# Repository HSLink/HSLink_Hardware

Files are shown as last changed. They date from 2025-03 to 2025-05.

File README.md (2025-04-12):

# HSLink_Hardware
用于存放历史HSLink的硬件工程。

## Release Note:

### v1.0

* 初版

### v1.2.0

* 修改了WS2812管脚，与串口控制脚交换，以使用SPI
* 使用负载开关替换替换mos来控制对外输出

### v1.2.1

* 更换负载开关以提高smt良率

### v1.3.1

* 修改外观适配外壳
* 使用sepic替换buck以避免输入5v时输出达不到5v
* 依旧使用mos控制tvcc输出
* 修复下载时可能出现的串口乱码
* 添加io失能串口输出

## 内嵌字体下载

[MiSans](https://hyperos.mi.com/font/download)

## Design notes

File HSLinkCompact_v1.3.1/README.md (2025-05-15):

# HSLinkPro

适配鹿小班等外壳。

## KiCAD 版本

使用9.0以上版本的KiCAD打开。

## 制作指南

[制作指南](./ProductionGuide.md)

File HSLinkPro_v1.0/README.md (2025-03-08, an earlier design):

# HSLinkPro_v1.0

预售版本/第一版本，2024-08-29于淘宝睿赛德科技上架

## KiCAD 版本

使用8.0以上版本的KiCAD打开。

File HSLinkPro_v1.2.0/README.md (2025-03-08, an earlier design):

# HSLinkPro

## 本仓库不再更新！！

新的参考设计: <https://github.com/cherry-embedded/CherryDAP/tree/master/projects/HSLink-Pro/hardware>

HSLink Pro是一款基于HPM5301系列MCU的调试器。最高SWD/JTAG通信速率可达80M，并且拥有一路USB转串口，并带有DTR与RTS的输出，方便某些串口下载的MCU应用。

HSLink Pro软件参考<https://github.com/cherry-embedded/CherryDAP>。

## KiCAD 版本

使用8.0以上版本的KiCAD打开。

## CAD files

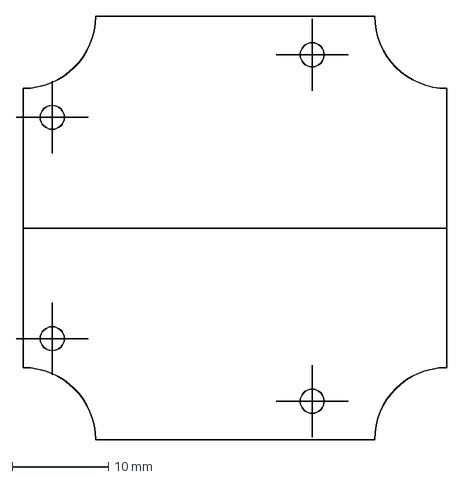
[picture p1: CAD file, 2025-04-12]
HSLinkCompact_v1.3.1/shape.dxf
44.8 x 44.0 mm

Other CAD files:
HSLinkCompact_v1.3.1/shape.DWG

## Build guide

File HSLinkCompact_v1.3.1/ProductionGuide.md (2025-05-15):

# 制作指南

## 制版及贴片

选择你喜欢的板厂打板。

根据自身情况选择smt或者手工焊接。

得到一块焊完的PCB。

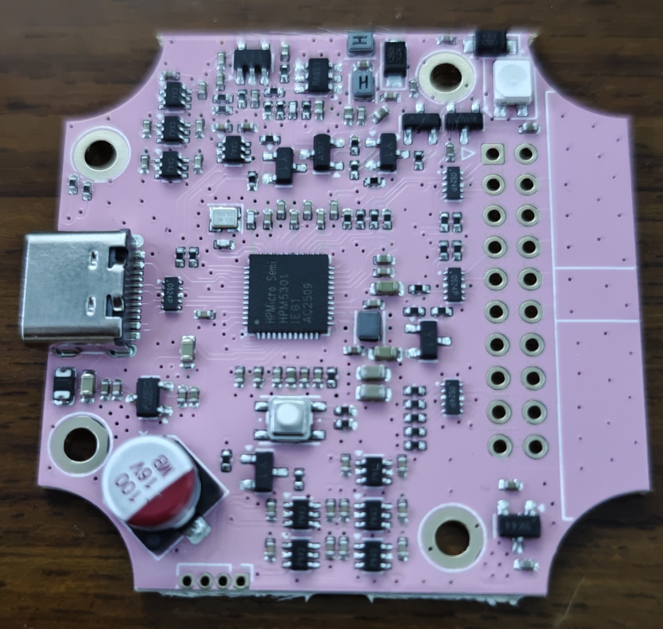
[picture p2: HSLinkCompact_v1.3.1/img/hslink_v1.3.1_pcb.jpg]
hslink_v1.3.1实物图


## 烧录线连接

使用1.27的测试夹，或是直接焊线，将USB转串口连接到PCB左下角的烧录点。参照背面对应位置的丝印，GND连接GND，TX接RX，RX接TX，3V不连接。

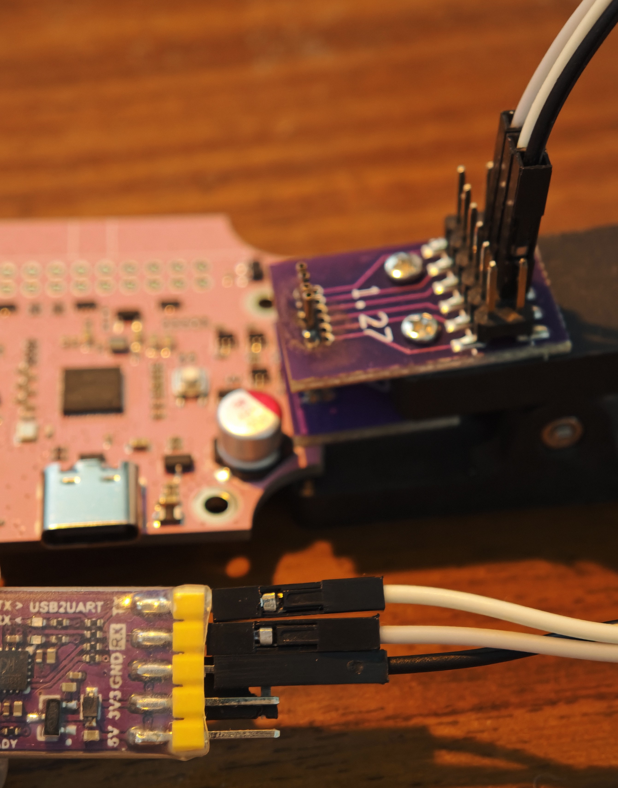
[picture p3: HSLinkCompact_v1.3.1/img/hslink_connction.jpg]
hslink_connction


## 连接电脑烧录

按住按键后插入PCB的Type-C接口，再插入USB转串口的USB接口。

打开HPM的上位机选择对应的串口，速率拉高后点击连接

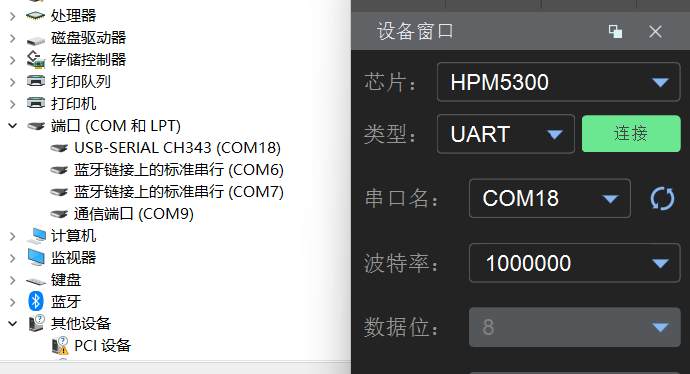
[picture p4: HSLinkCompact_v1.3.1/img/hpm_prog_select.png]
hpmprog


选择固件压缩包中的Merge.bin文件，点击烧写。

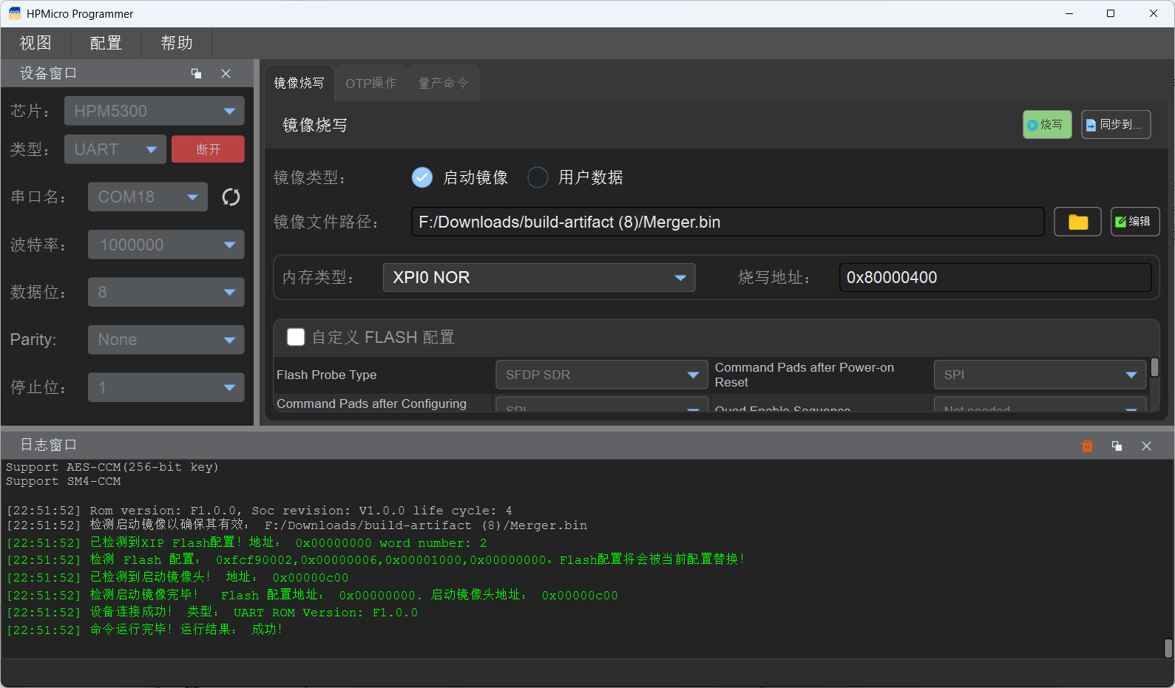
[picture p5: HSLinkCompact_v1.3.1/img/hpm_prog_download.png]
hpm_prog_download


切换到OTP页面，烧写版本号。注意OTP仅能进行一次烧写。

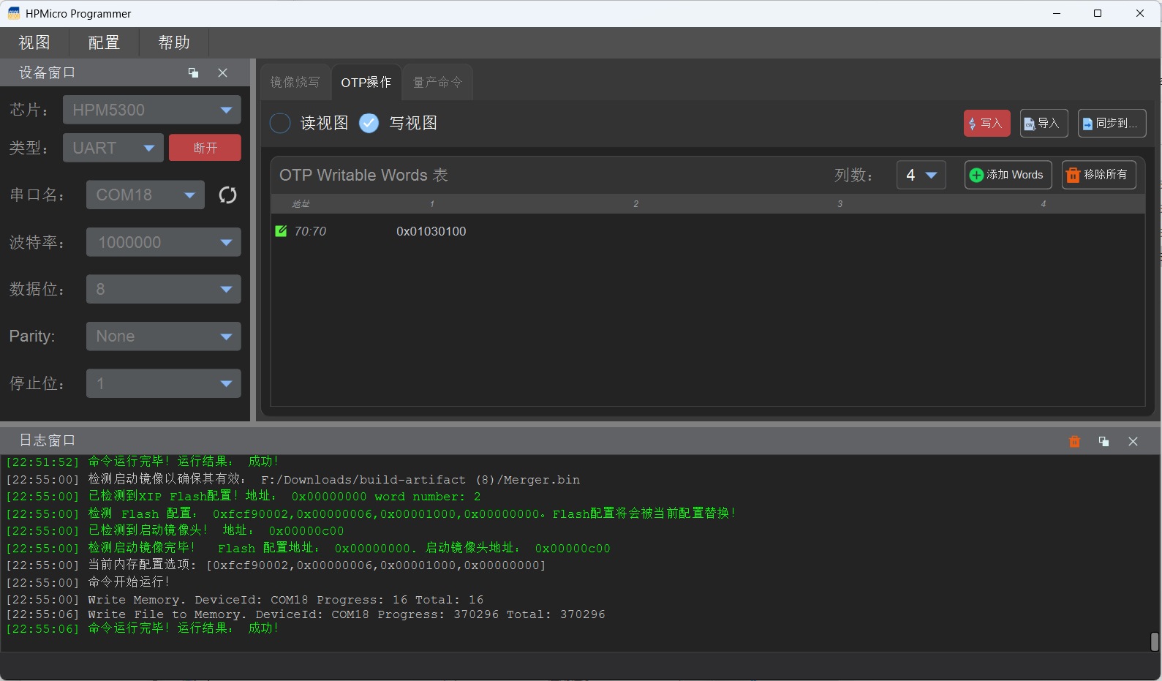
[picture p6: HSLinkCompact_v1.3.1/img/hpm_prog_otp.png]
hpm_prog_otp


## 连接上位机

拔掉调试器再插入，即可连接到上位机

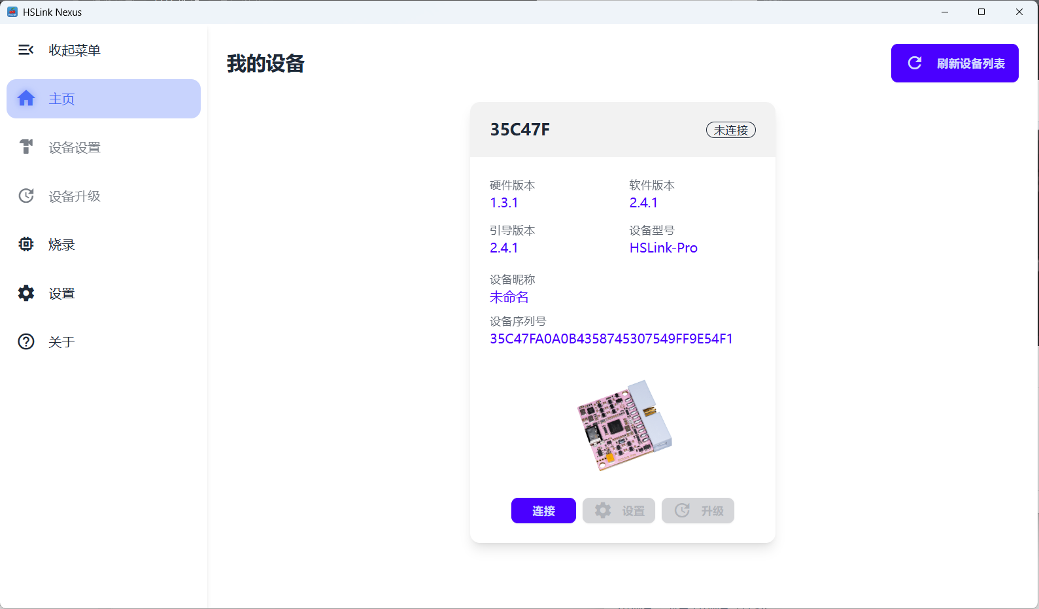
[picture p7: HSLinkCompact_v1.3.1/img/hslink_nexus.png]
hslink_nexus


## 外壳

可配合鹿小班等外壳，使用M2.2*4的自攻螺丝进行固定。

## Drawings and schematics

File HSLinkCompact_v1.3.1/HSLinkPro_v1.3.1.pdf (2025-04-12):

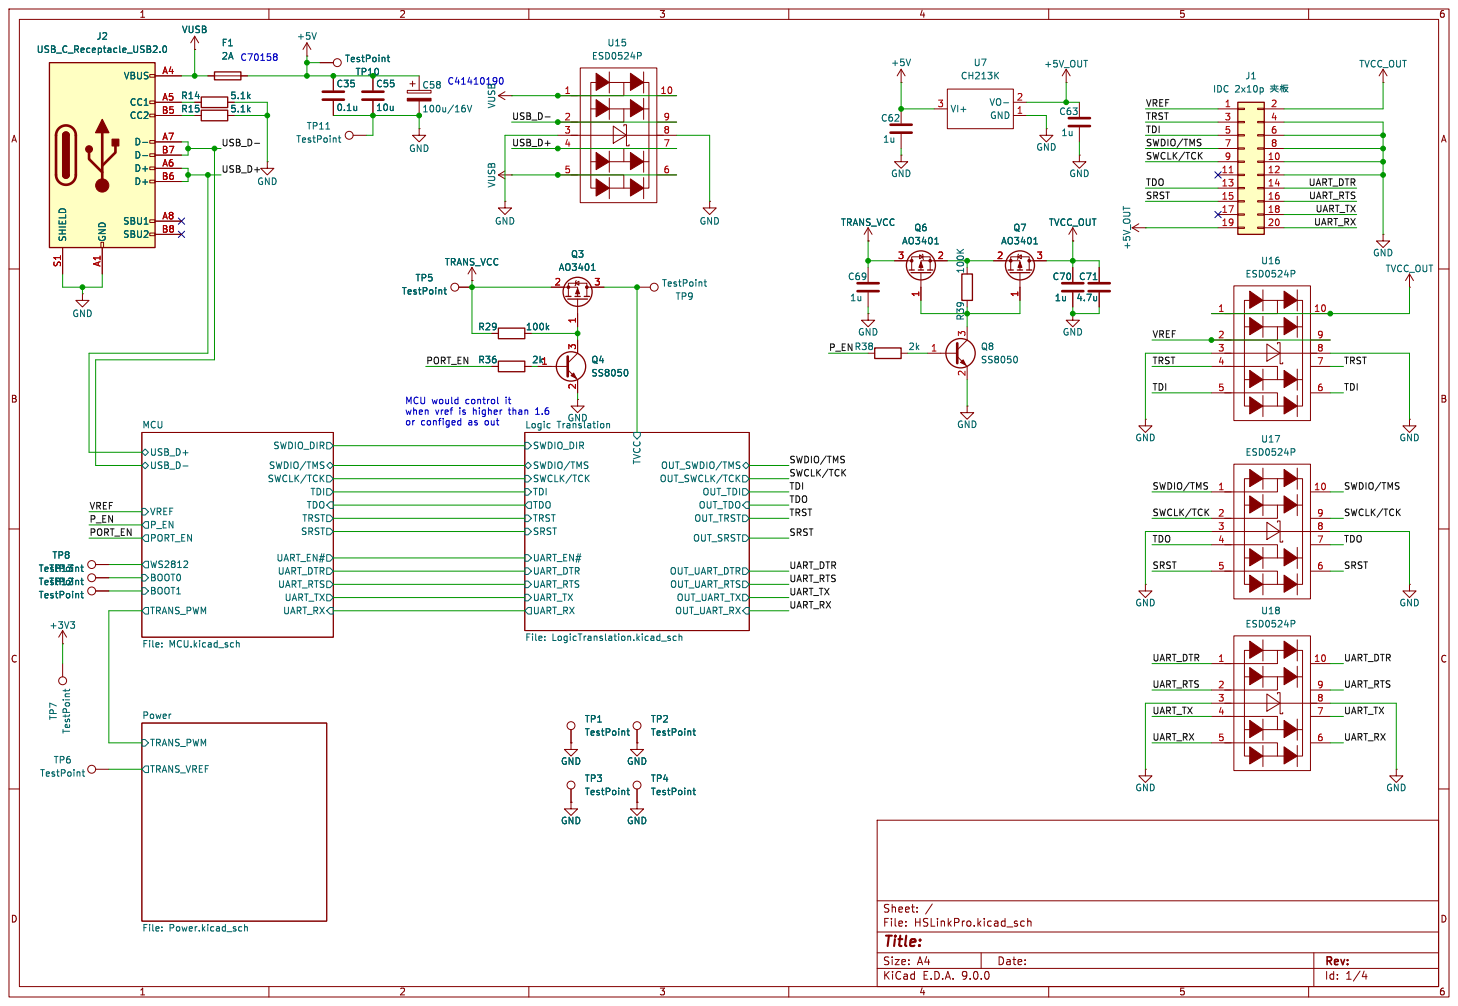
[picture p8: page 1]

Logic Translation File: LogicTranslation.kicad_sch TRANS_PWM

Id: 1/4 Title: File: HSLinkPro.kicad_sch Sheet: /

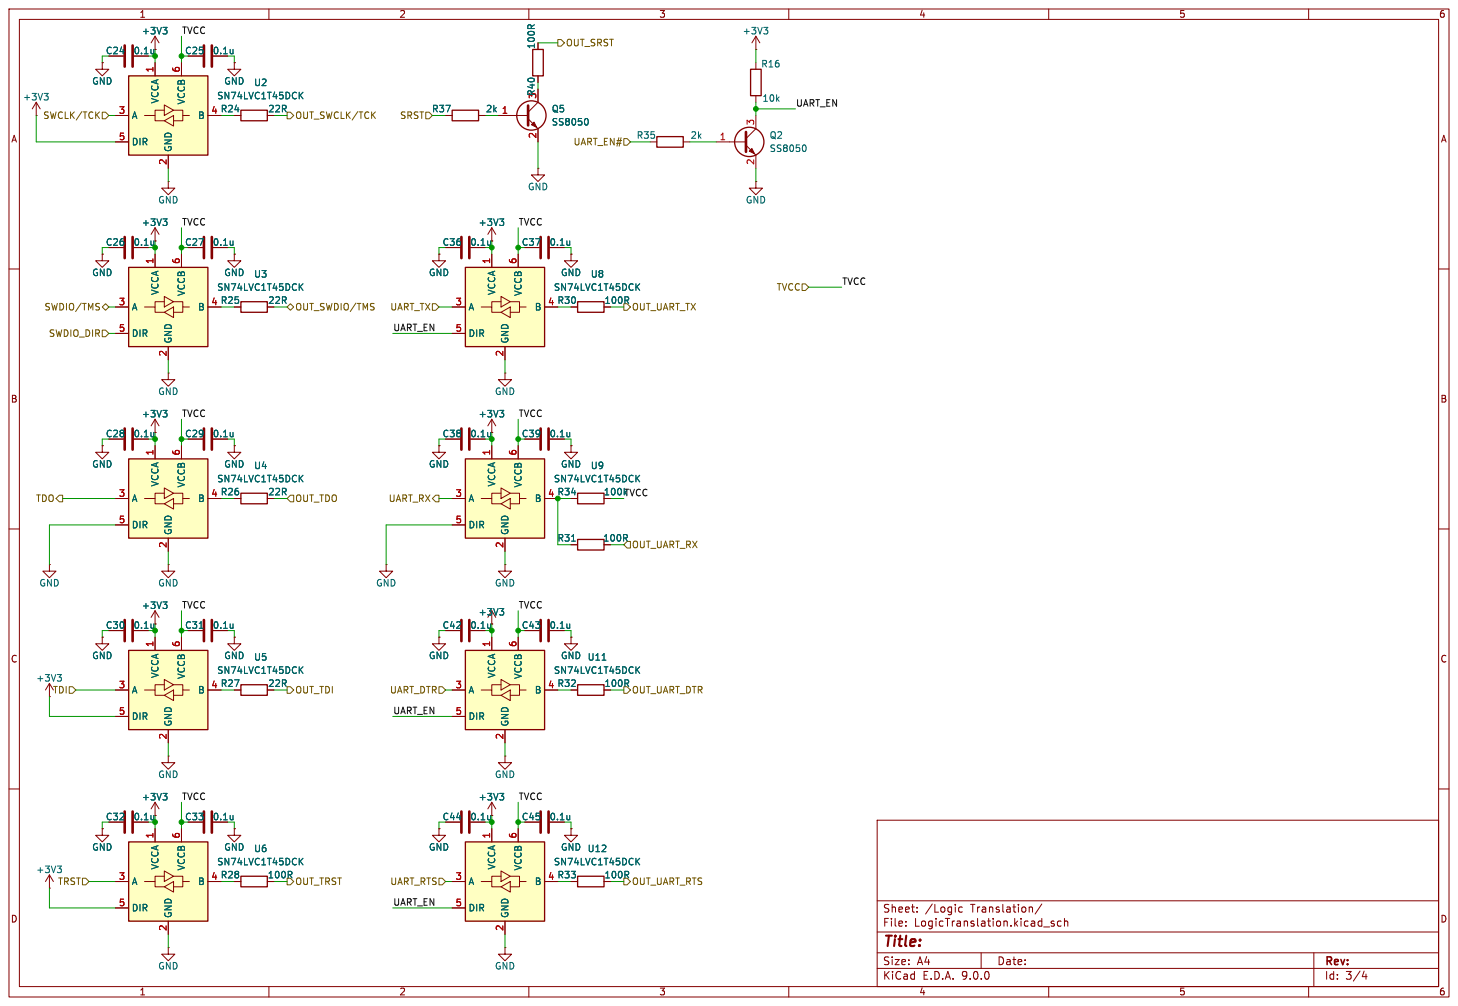
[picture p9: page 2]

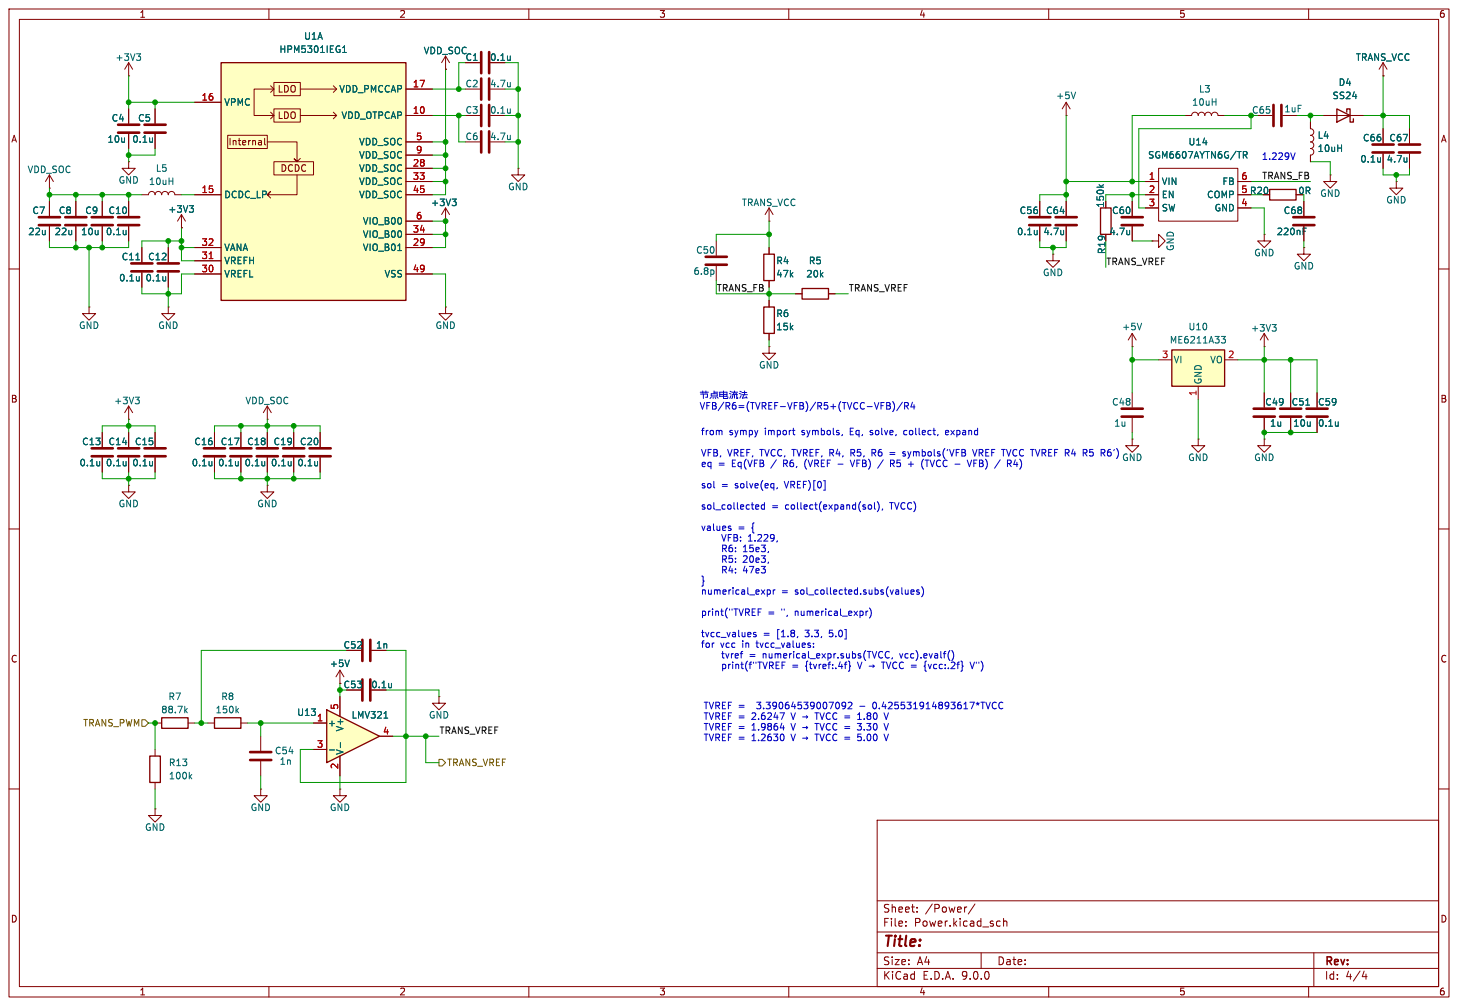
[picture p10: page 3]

þÿ‚‚p¹u5mAlÕ
VFB/R6=(TVREF-VFB)/R5+(TVCC-VFB)/R4

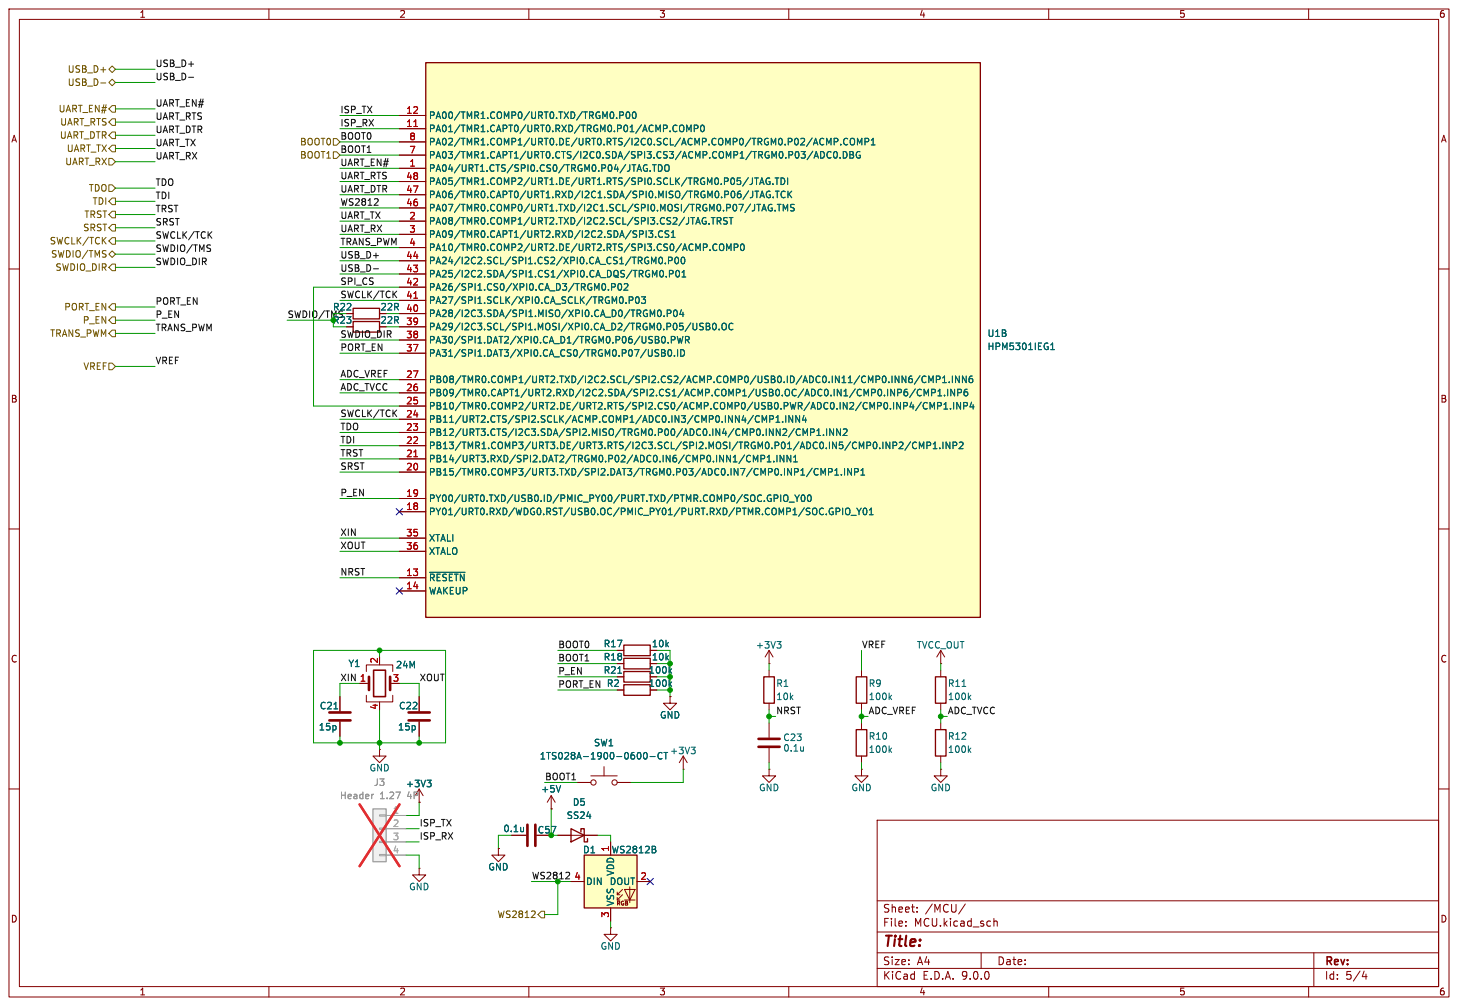
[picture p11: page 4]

TRST SRST SWDIO/TMS

Id: 5/4 Title: File: MCU.kicad_sch Sheet: /MCU/ R11

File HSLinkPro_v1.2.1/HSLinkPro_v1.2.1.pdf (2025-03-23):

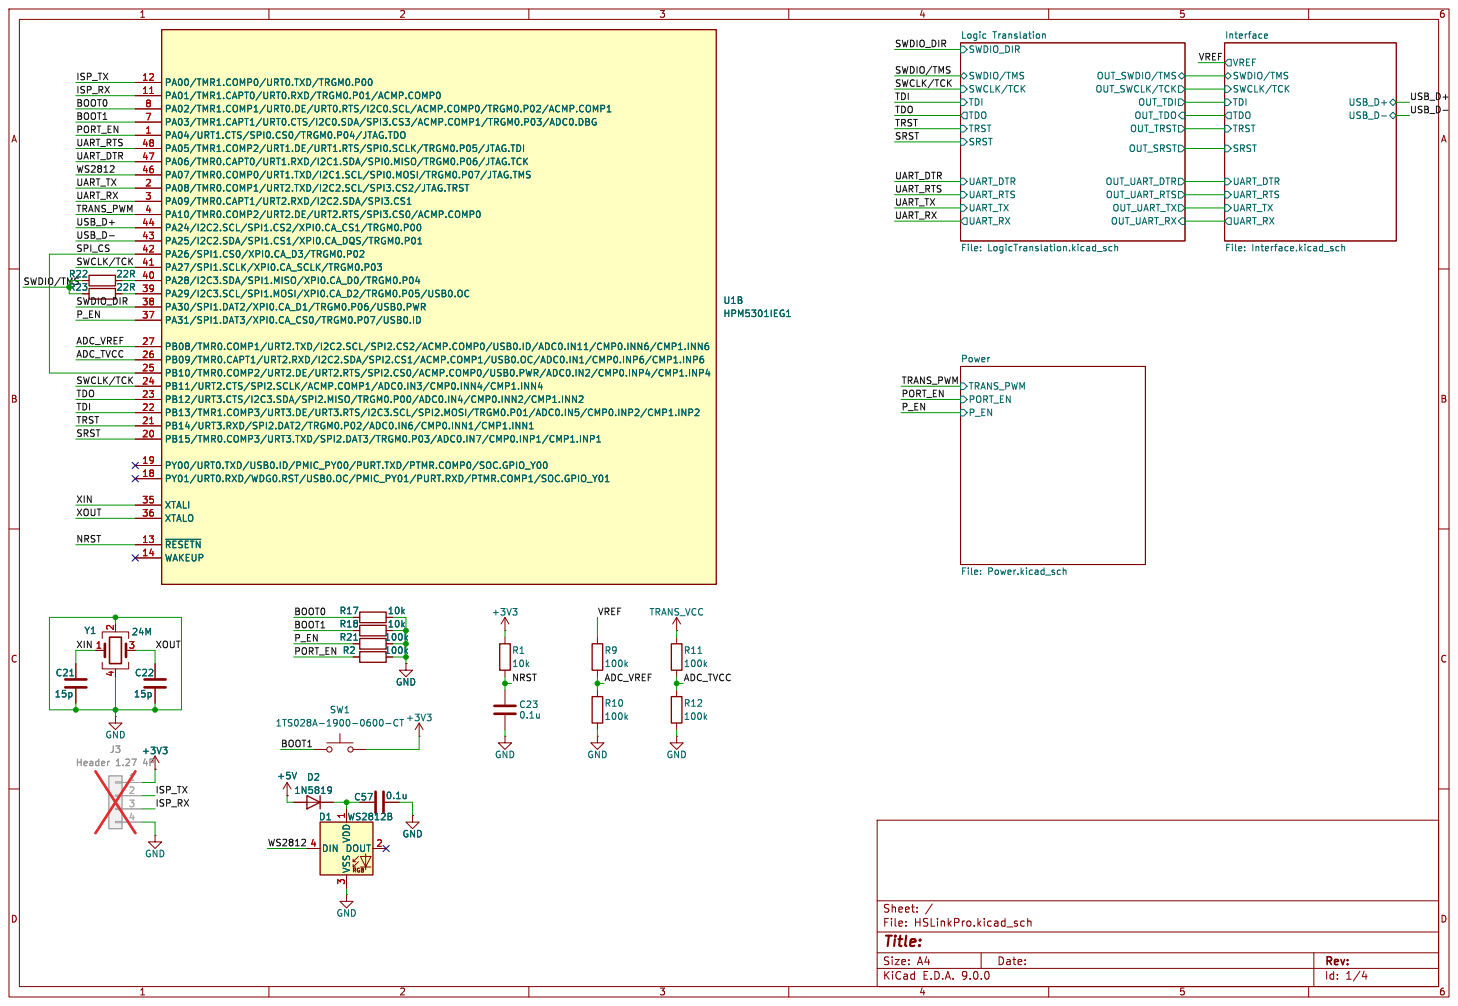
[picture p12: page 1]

Id: 1/4 Title: File: HSLinkPro.kicad_sch Sheet: /

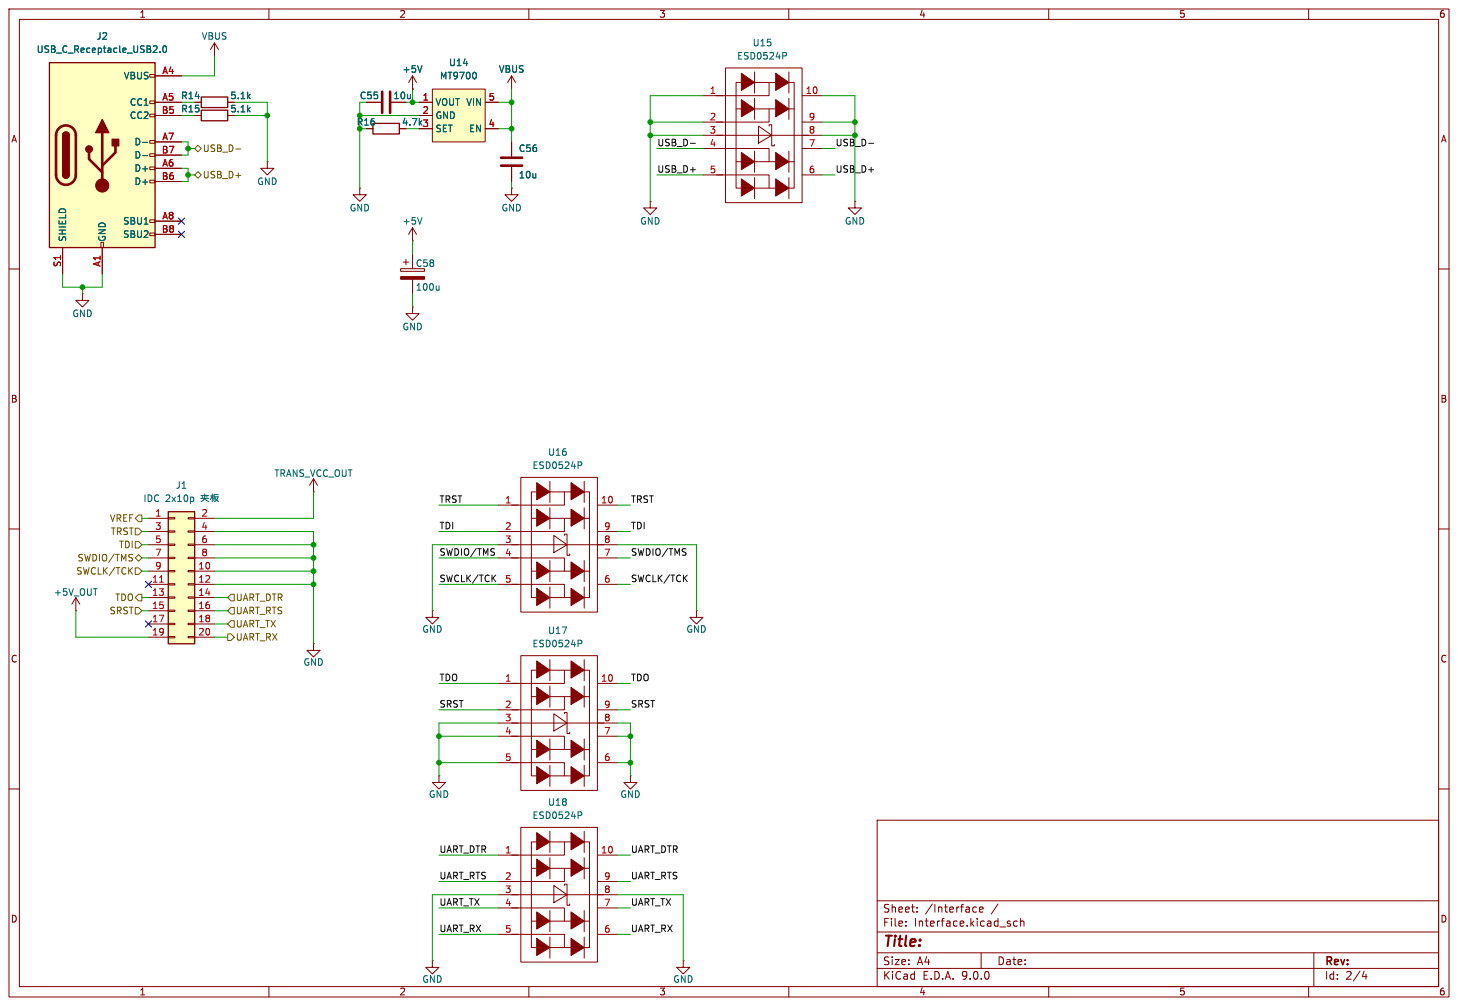
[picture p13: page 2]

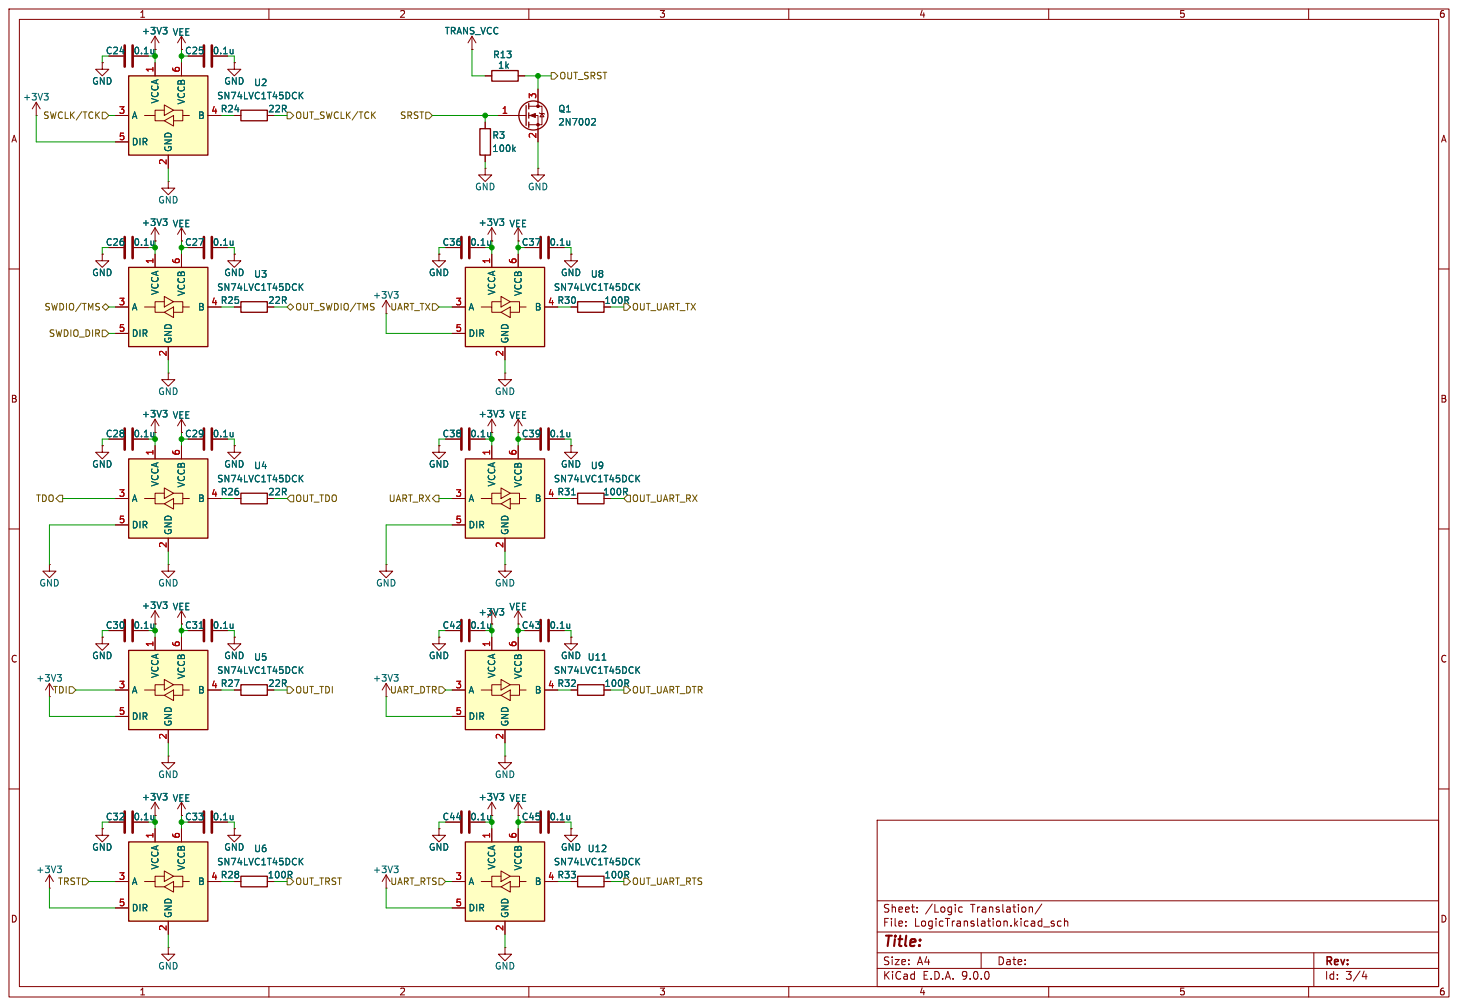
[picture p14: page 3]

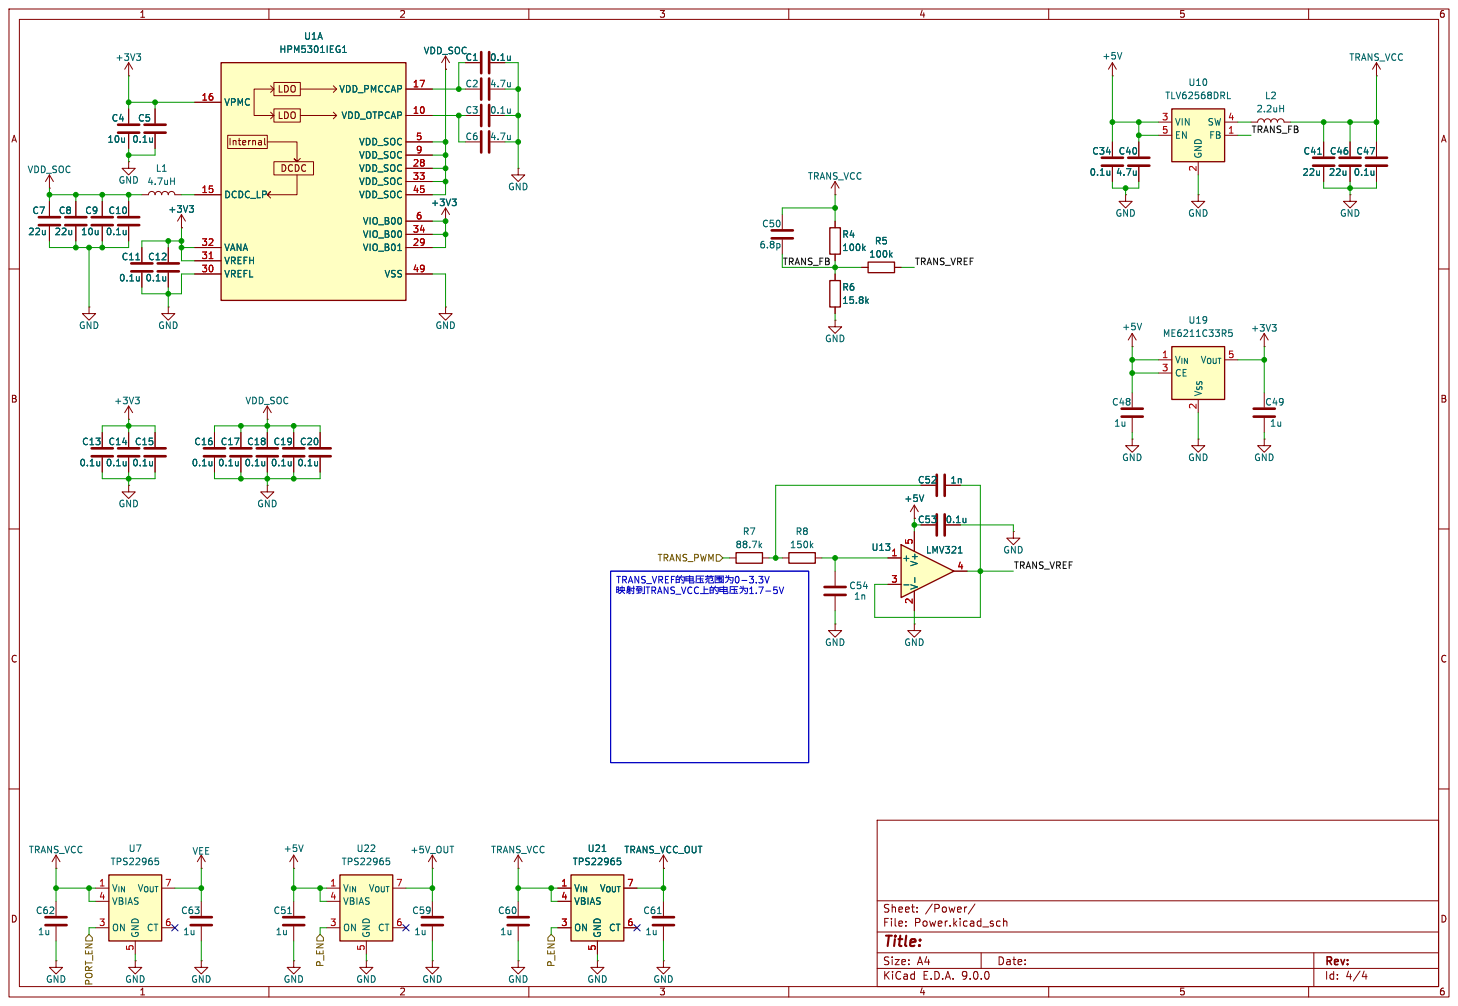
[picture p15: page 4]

2 SW 4 FB 1 U10 TLV62568DRL GND GND

Id: 4/4 Title: File: Power.kicad_sch Sheet: /Power/

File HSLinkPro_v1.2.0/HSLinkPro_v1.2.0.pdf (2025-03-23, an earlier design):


Id: 1/4 Title: File: HSLinkPro.kicad_sch Sheet: /



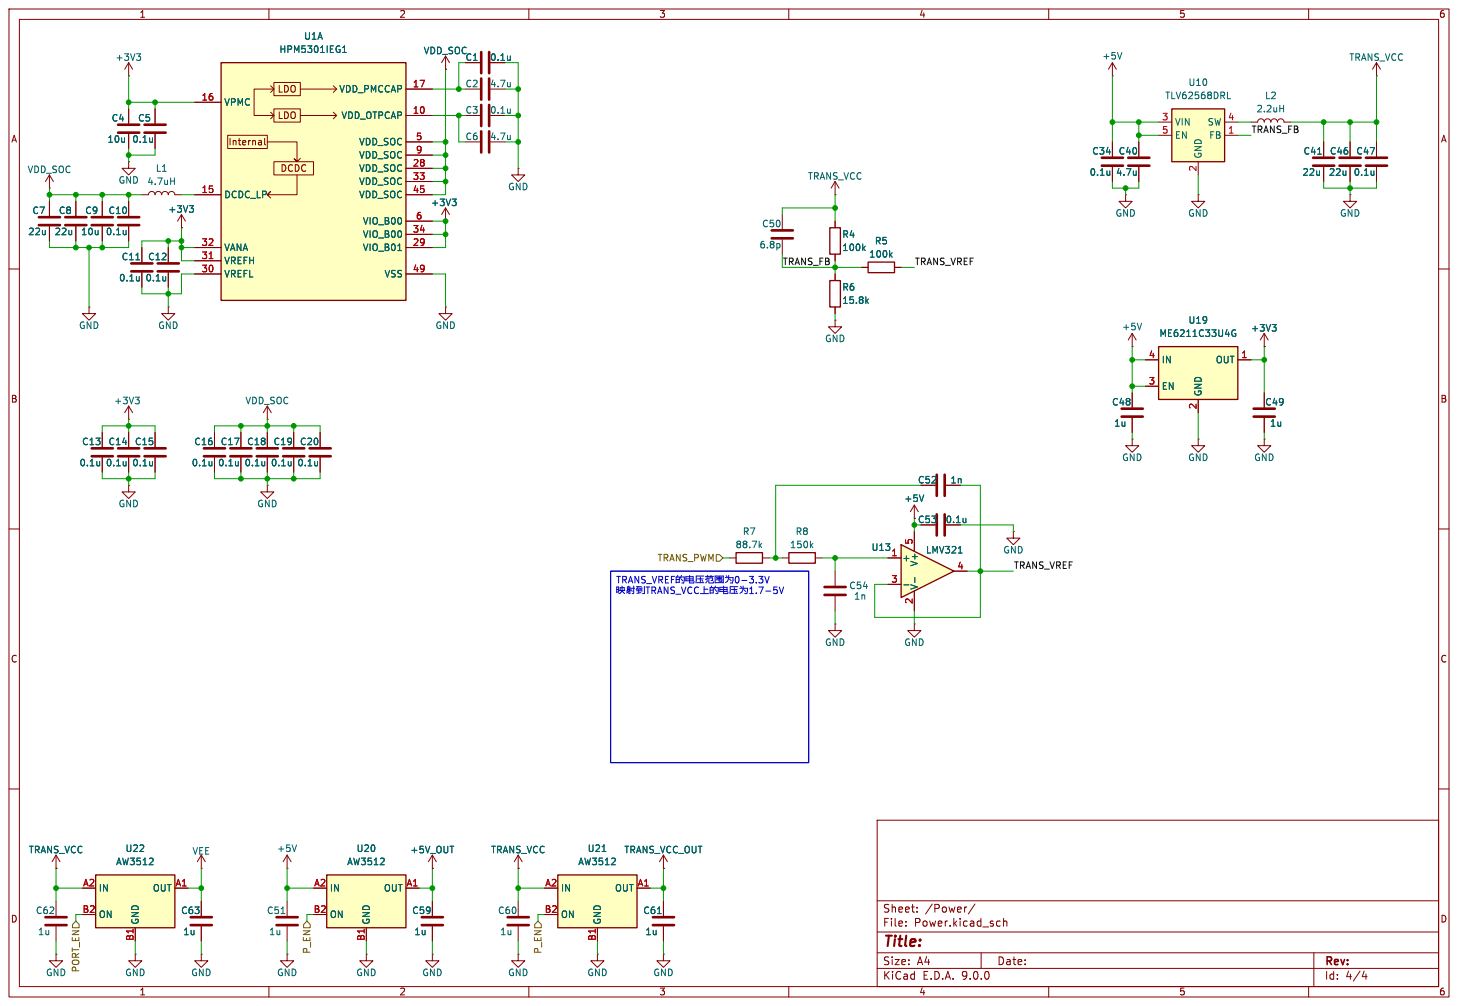
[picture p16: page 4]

Id: 4/4 Title: File: Power.kicad_sch Sheet: /Power/

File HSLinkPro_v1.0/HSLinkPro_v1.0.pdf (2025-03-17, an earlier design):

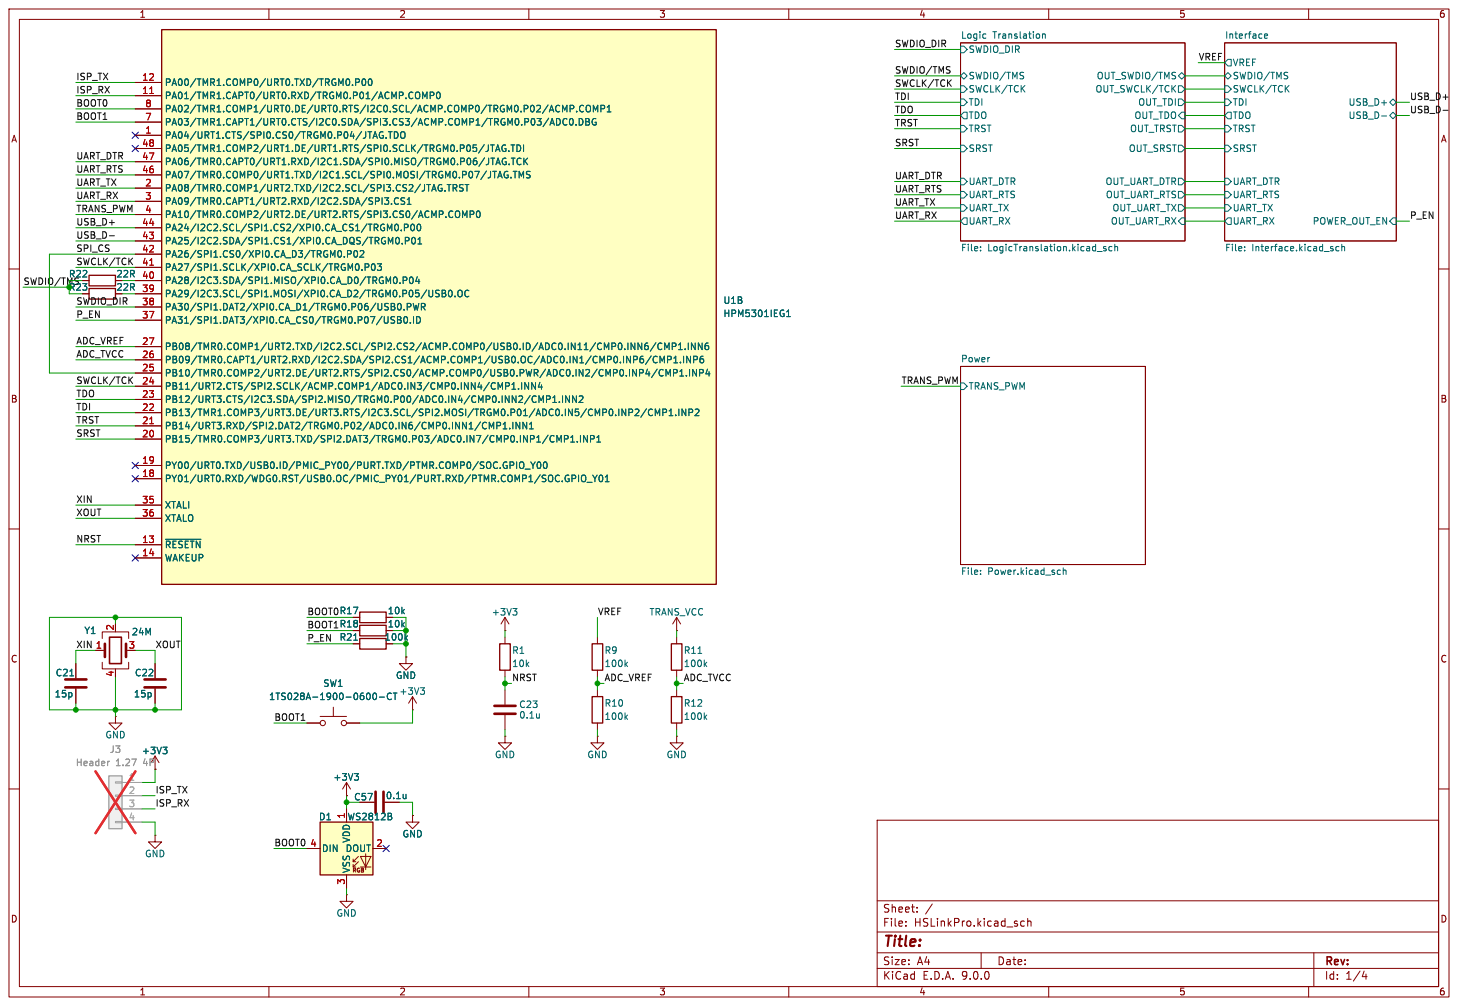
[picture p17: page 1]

Id: 1/4 Title: File: HSLinkPro.kicad_sch Sheet: /

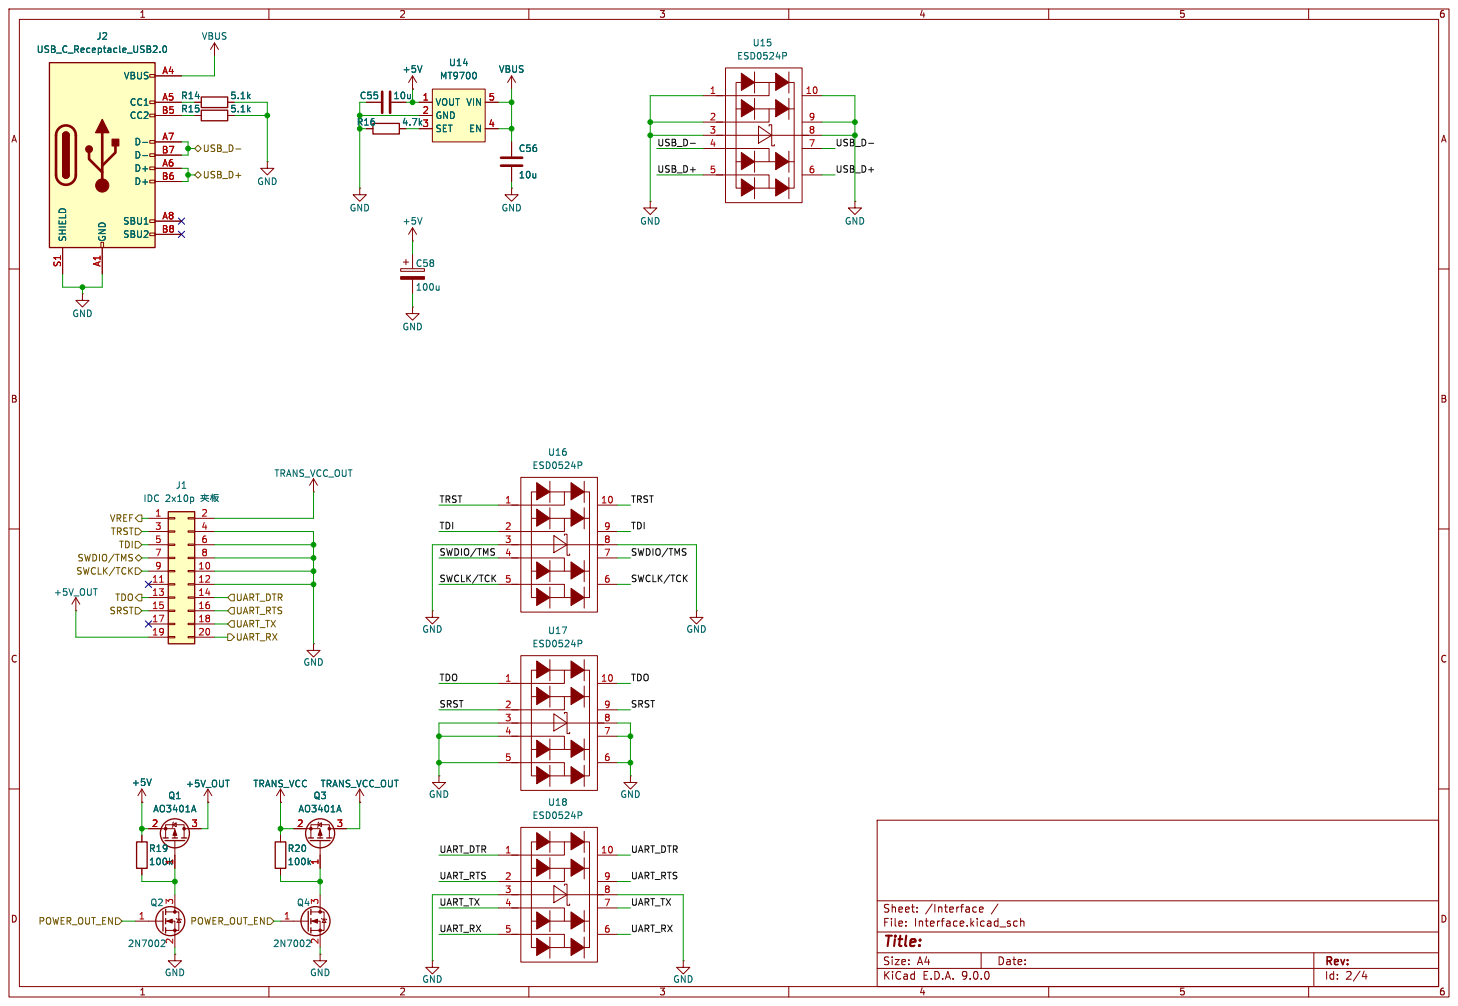
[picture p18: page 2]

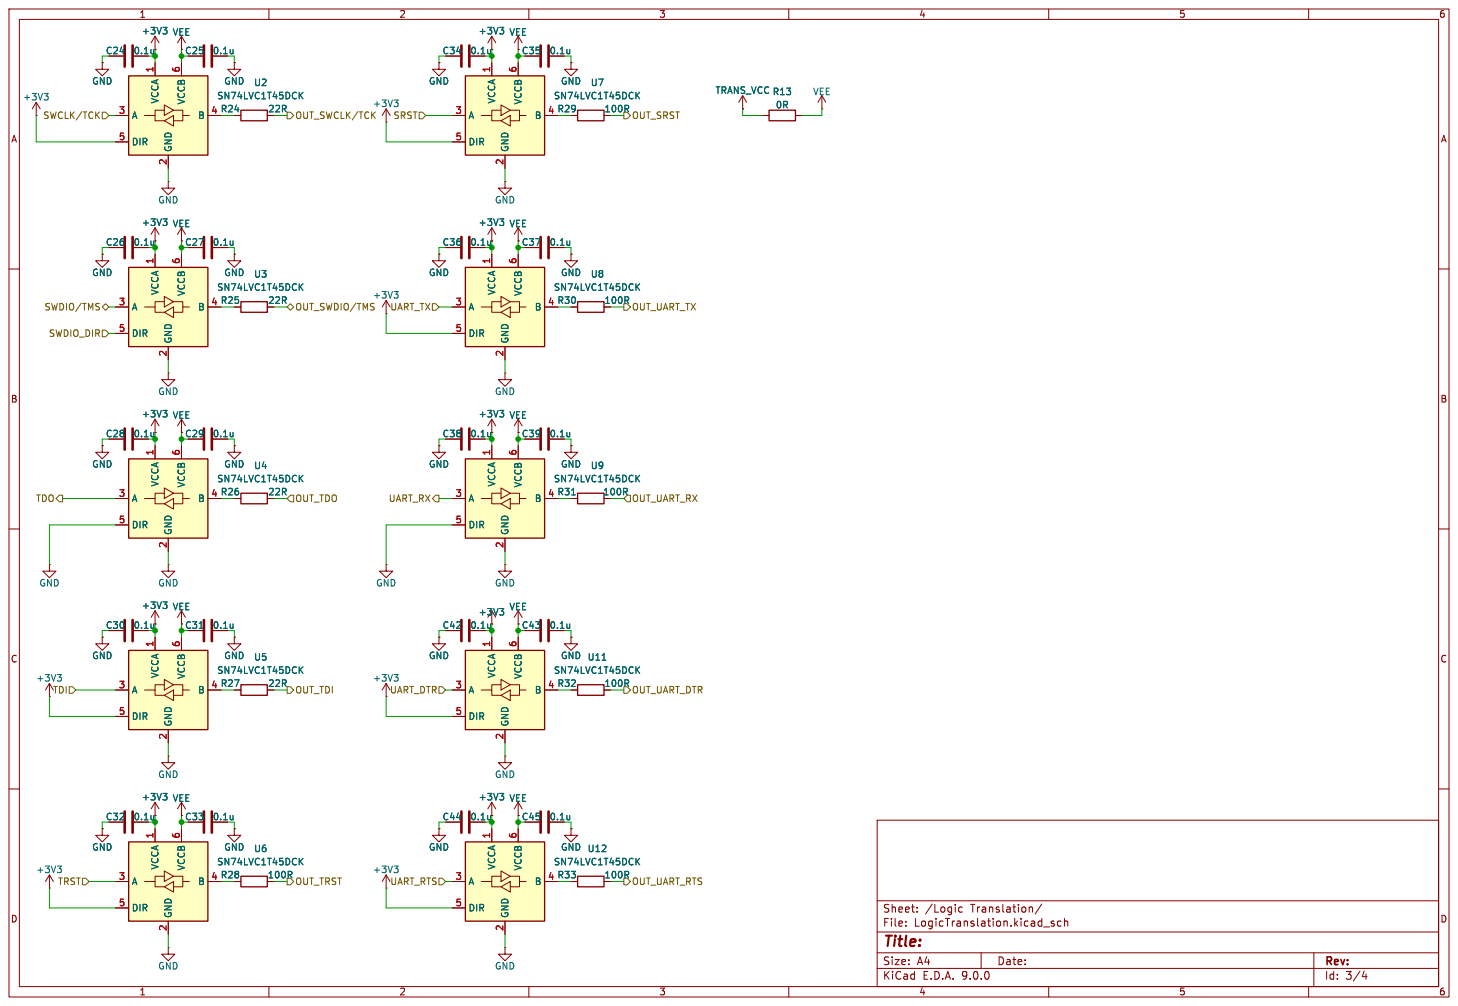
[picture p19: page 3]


Id: 4/4 Title: File: Power.kicad_sch Sheet: /Power/

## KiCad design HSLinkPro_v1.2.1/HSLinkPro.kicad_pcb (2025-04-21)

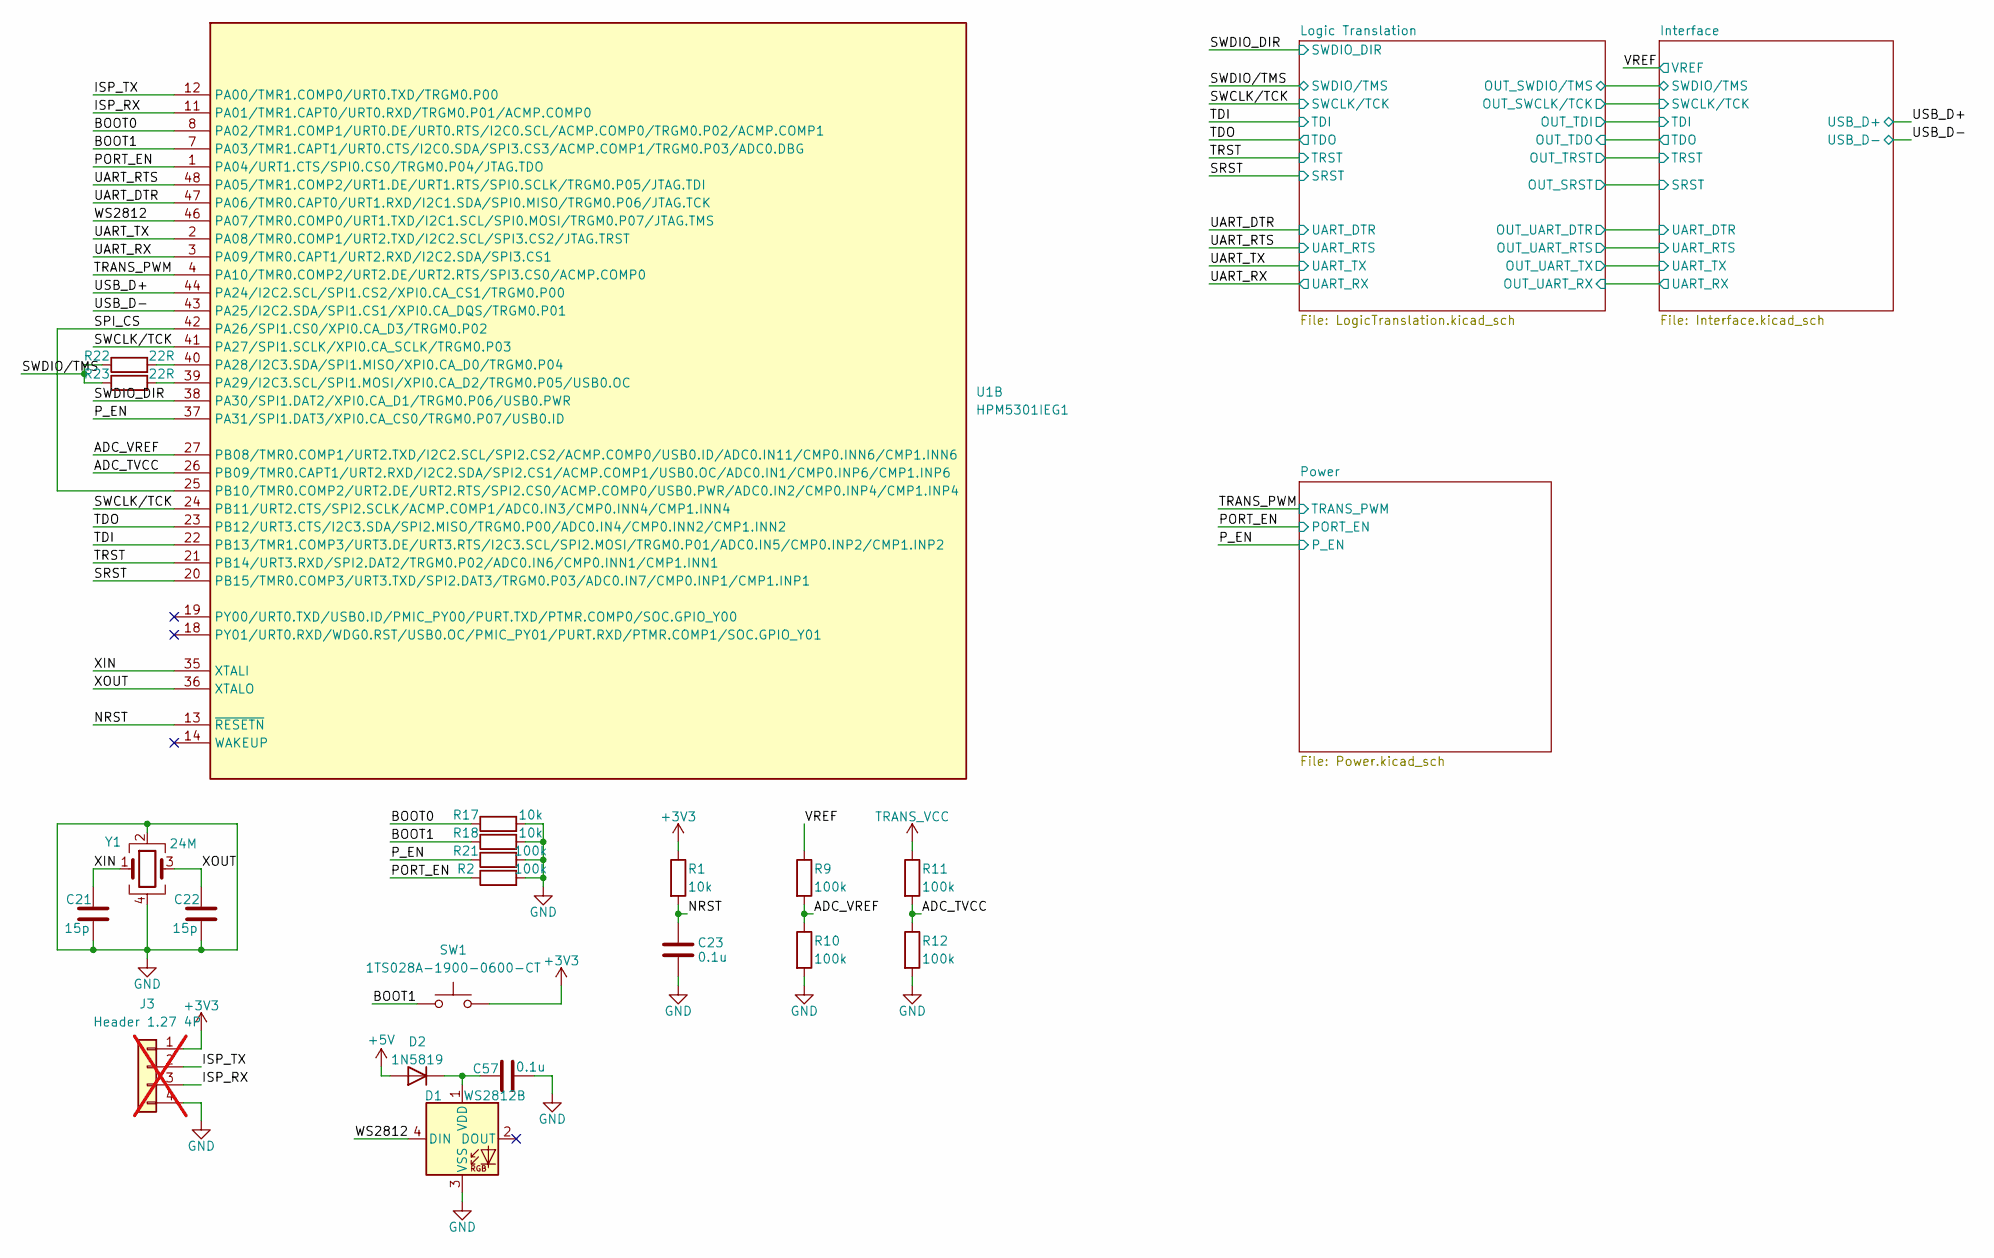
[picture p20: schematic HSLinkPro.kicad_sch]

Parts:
C21, C22: 15p; C_0402_1005Metric
C23, C57: 0.1u; C_0402_1005Metric
D1: WS2812B; LED_WS2812_0807
D2: 1N5819; D_SOD-523
J3: Header 1.27 4P; PinHeader_1x04_P1.27mm_Vertical; not fitted
R1, R17, R18: 10k; R_0402_1005Metric
R2, R9, R10, R11, R12, R21: 100k; R_0402_1005Metric
R22, R23: 22R; R_0402_1005Metric
SW1: 1TS028A-1900-0600-CT; SW-SMD_4P-L2.8-W1.9-P1.20-LS3.0_1TS028A
U1: HPM5301IEG1; QFN-48-1EP_6x6mm_P0.4mm_EP4.2x4.2mm
Y1: 24M; Crystal_SMD_2016-4Pin_2.0x1.6mm

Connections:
+3V3: J3.1, R1.1, SW1.2; also elsewhere on the board
+5V: D2.2 (A); also elsewhere on the board
/ADC_TVCC: R11.2, R12.1, U1.26 (PB09/TMR0.CAPT1/URT2.RXD/I2C2.SDA/SPI2.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)
/ADC_VREF: R9.2, R10.1, U1.27 (PB08/TMR0.COMP1/URT2.TXD/I2C2.SCL/SPI2.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)
/BOOT0: R17.1, U1.8 (PA02/TMR1.COMP1/URT0.DE/URT0.RTS/I2C0.S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)
/BOOT1: R18.1, SW1.1, U1.7 (PA03/TMR1.CAPT1/URT0.CTS/I2C0.SDA/SPI3.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)
/ISP_RX: J3.3, U1.11 (PA01/TMR1.CAPT0/URT0.RXD/TRGM0.P01/ACMP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)
/ISP_TX: J3.2, U1.12 (PA00/TMR1.COMP0/URT0.TXD/TRGM0.P00)
/NRST: C23.1, R1.2, U1.13 (~RESETN)
/PORT_EN: R2.1, U1.1 (PA04/URT1.CTS/SPI0.CS0/TRGM0.P04/JTAG.T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); also elsewhere on the board
/P_EN: R21.1, U1.37 (PA31/SPI1.DAT3/XPI0.CA_CS0/TRGM0.P07/US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); also elsewhere on the board
/SPI_CS: U1.25 (PB10/TMR0.COMP2/URT2.DE/URT2.RTS/SPI2.C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), U1.42 (PA26/SPI1.CS0/XPI0.CA_D3/TRGM0.P02)
/SRST: U1.20 (PB15/TMR0.COMP3/URT3.TXD/SPI2.DAT3/TRGM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); also elsewhere on the board
/SWCLK/TCK: U1.24 (PB11/URT2.CTS/SPI2.SCLK/ACMP.COMP1/ADC0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), U1.41 (PA27/SPI1.SCLK/XPI0.CA_SCLK/TRGM0.P03); also elsewhere on the board
/SWDIO_DIR: U1.38 (PA30/SPI1.DAT2/XPI0.CA_D1/TRGM0.P06/USB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); also elsewhere on the board
/SWDIO/TMS: R22.1, R23.1; also elsewhere on the board
/TDI: U1.22 (PB13/TMR1.COMP3/URT3.DE/URT3.RTS/I2C3.S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); also elsewhere on the board
/TDO: U1.23 (PB12/URT3.CTS/I2C3.SDA/SPI2.MISO/TRGM0.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); also elsewhere on the board
/TRANS_PWM: U1.4 (PA10/TMR0.COMP2/URT2.DE/URT2.RTS/SPI3.C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); also elsewhere on the board
/TRST: U1.21 (PB14/URT3.RXD/SPI2.DAT2/TRGM0.P02/ADC0.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); also elsewhere on the board
/UART_DTR: U1.47 (PA06/TMR0.CAPT0/URT1.RXD/I2C1.SDA/SPI0.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); also elsewhere on the board
/UART_RTS: U1.48 (PA05/TMR1.COMP2/URT1.DE/URT1.RTS/SPI0.S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); also elsewhere on the board
/UART_RX: U1.3 (PA09/TMR0.CAPT1/URT2.RXD/I2C2.SDA/SPI3.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); also elsewhere on the board
/UART_TX: U1.2 (PA08/TMR0.COMP1/URT2.TXD/I2C2.SCL/SPI3.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); also elsewhere on the board
/USB_D+: U1.44 (PA24/I2C2.SCL/SPI1.CS2/XPI0.CA_CS1/TRGM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); also elsewhere on the board
/USB_D-: U1.43 (PA25/I2C2.SDA/SPI1.CS1/XPI0.CA_DQS/TRGM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); also elsewhere on the board
/VREF: R9.1; also elsewhere on the board
/WS2812: D1.4 (DIN), U1.46 (PA07/TMR0.COMP0/URT1.TXD/I2C1.SCL/SPI0.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)
/XIN: C21.1, U1.35 (XTALI), Y1.1
/XOUT: C22.1, U1.36 (XTALO), Y1.3
GND: C21.2, C22.2, C23.2, C57.2, D1.3 (VSS), J3.4, R2.2, R10.2, R12.2, R17.2, R18.2, R21.2, Y1.2, Y1.4; also elsewhere on the board
unnamed: C57.1, D1.1 (VDD), D2.1 (K)
unnamed: R22.2, U1.40 (PA28/I2C3.SDA/SPI1.MISO/XPI0.CA_D0/TRGM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)
unnamed: R23.2, U1.39 (PA29/I2C3.SCL/SPI1.MOSI/XPI0.CA_D2/TRGM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)
TRANS_VCC: R11.1; also elsewhere on the board

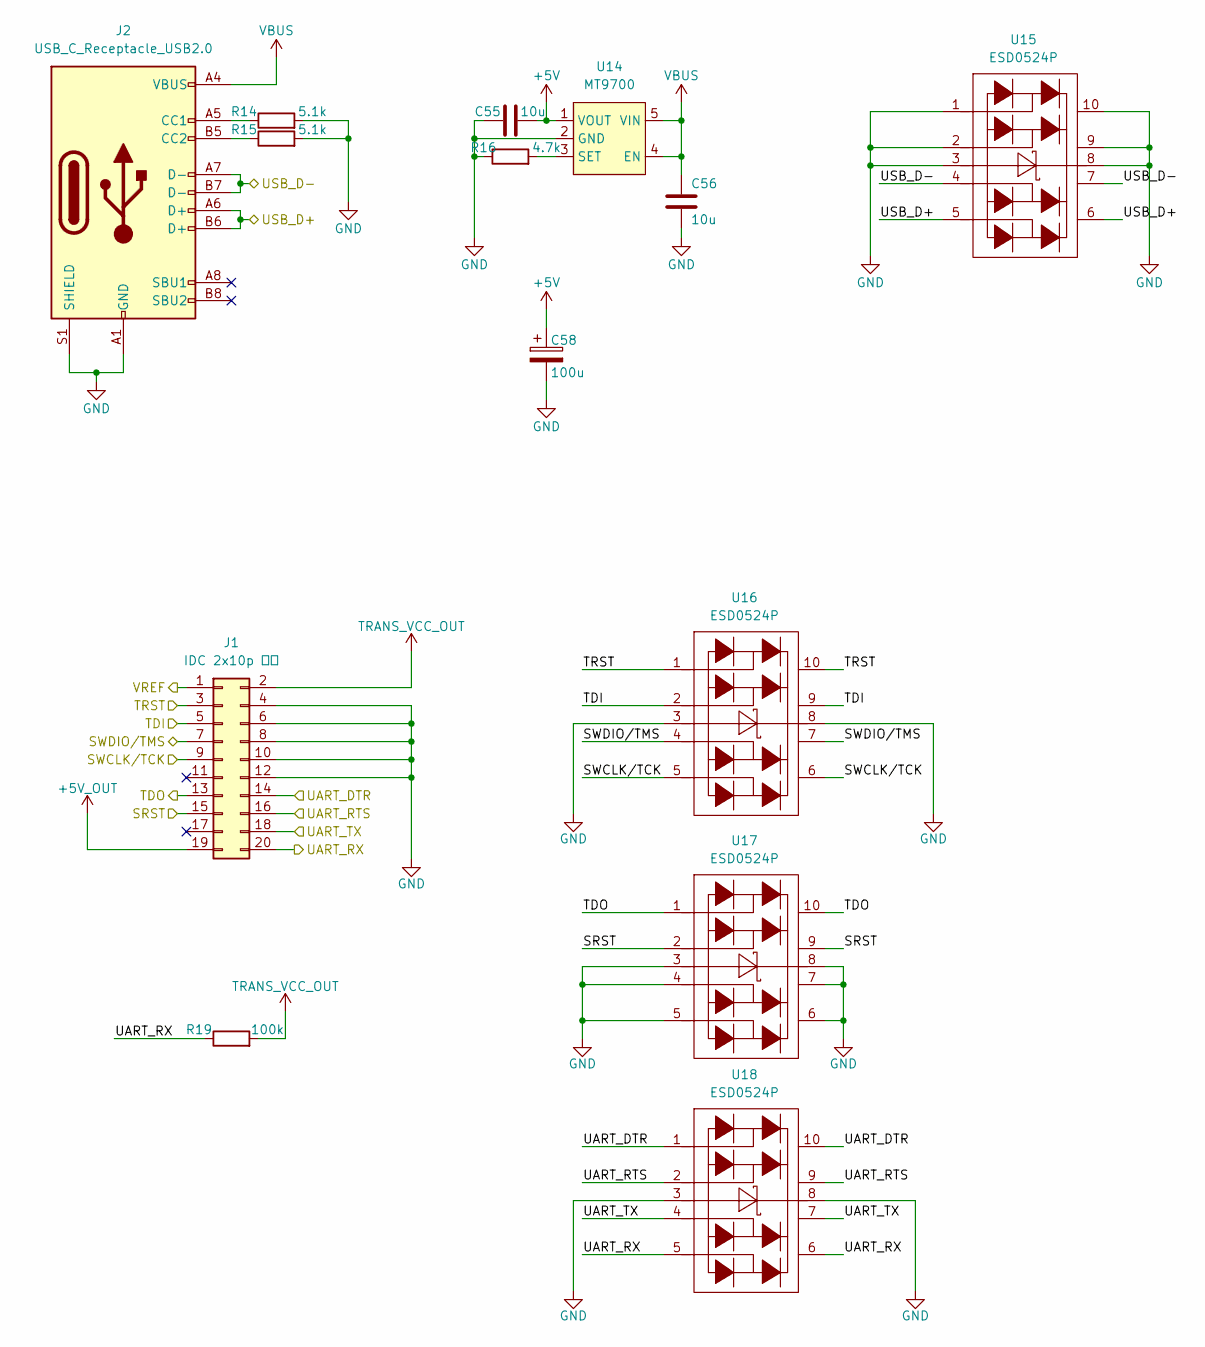
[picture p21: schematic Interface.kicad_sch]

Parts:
C55, C56: 10u; C_0603_1608Metric
C58: 100u; CP_EIA-3528-21_Kemet-B
J1: IDC 2x10p 夹板; Conn_02x10_IDC_SMD
J2: USB_C_Receptacle_USB2.0; USB-C-SMD_CX90M-16P
R14, R15: 5.1k; R_0402_1005Metric
R16: 4.7k; R_0402_1005Metric
R19: 100k; R_0402_1005Metric
U14: MT9700; SOT-23-5
U15, U16, U17, U18: ESD0524P; DFN-10_L2.5-W1.0-P0.50-BL-A

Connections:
+5V: C55.2, C58.1, U14.1 (VOUT); also elsewhere on the board
+5V_OUT: J1.19; also elsewhere on the board
/Interface /<NO NET>: J1.5, U16.2, U16.9; also elsewhere on the board
/Interface /SRST: J1.15, U17.2, U17.9; also elsewhere on the board
/Interface /SWCLK/TCK: J1.9, U16.5, U16.6; also elsewhere on the board
/Interface /SWDIO/TMS: J1.7, U16.4, U16.7; also elsewhere on the board
/Interface /TDO: J1.13, U17.1, U17.10; also elsewhere on the board
/Interface /TRST: J1.3, U16.1, U16.10; also elsewhere on the board
/Interface /UART_DTR: J1.14, U18.1, U18.10; also elsewhere on the board
/Interface /UART_RTS: J1.16, U18.2, U18.9; also elsewhere on the board
/Interface /UART_RX: J1.20, R19.1, U18.5, U18.6; also elsewhere on the board
/Interface /UART_TX: J1.18, U18.4, U18.7; also elsewhere on the board
/USB_D+: J2.A6 (D+), J2.B6 (D+), U15.5, U15.6; also elsewhere on the board
/USB_D-: J2.A7 (D-), J2.B7 (D-), U15.4, U15.7; also elsewhere on the board
/VREF: J1.1; also elsewhere on the board
GND: C55.1, C56.2, C58.2, J1.4, J1.6, J1.8, J1.10, J1.12, J2.A1 (GND), J2.A12 (GND), J2.B1 (GND), J2.B12 (GND), J2.S1 (SHIELD), R14.2, R15.2, R16.1, U14.2 (GND), U15.1, U15.2, U15.3, U15.8, U15.9, U15.10, U16.3, U16.8, U17.3, U17.4, U17.5, U17.6, U17.7, U17.8, U18.3, U18.8; also elsewhere on the board
unnamed: J2.A5 (CC1), R14.1
unnamed: J2.B5 (CC2), R15.1
unnamed: R16.2, U14.3 (SET)
TRANS_VCC_OUT: J1.2, R19.2; also elsewhere on the board
VBUS: C56.1, J2.A4 (VBUS), J2.A9 (VBUS), J2.B4 (VBUS), J2.B9 (VBUS), U14.4 (EN), U14.5 (VIN)

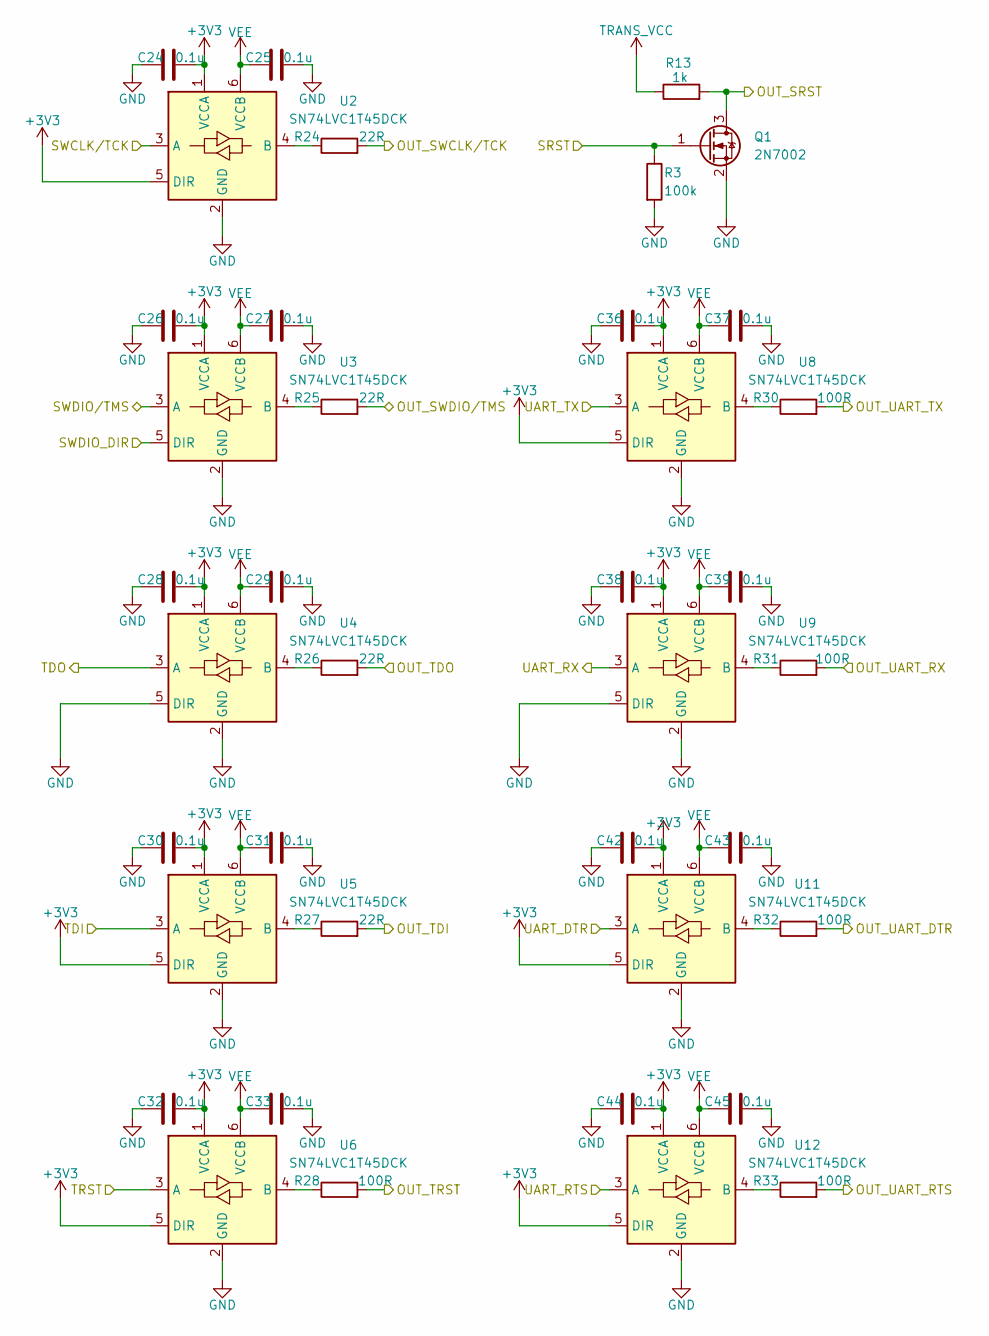
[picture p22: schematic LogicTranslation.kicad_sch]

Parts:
C24, C25, C26, C27, C28, C29, C30, C31, C32, C33, C36, C37, C38, C39, C42, C43, C44, C45: 0.1u; C_0402_1005Metric
Q1: 2N7002; SOT-323_SC-70
R3: 100k; R_0402_1005Metric
R13: 1k; R_0402_1005Metric
R24, R25, R26, R27: 22R; R_0402_1005Metric
R28, R30, R31, R32, R33: 100R; R_0402_1005Metric
U2, U3, U4, U5, U6, U8, U9, U11, U12: SN74LVC1T45DCK; SOT-363_SC-70-6

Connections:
+3V3: C24.2, C26.2, C28.2, C30.2, C32.2, C36.2, C38.2, C42.2, C44.2, U2.1 (VCCA), U2.5 (DIR), U3.1 (VCCA), U4.1 (VCCA), U5.1 (VCCA), U5.5 (DIR), U6.1 (VCCA), U6.5 (DIR), U8.1 (VCCA), U8.5 (DIR), U9.1 (VCCA), U11.1 (VCCA), U11.5 (DIR), U12.1 (VCCA), U12.5 (DIR); also elsewhere on the board
/Interface /<NO NET>: R27.2; also elsewhere on the board
/Interface /SRST: Q1.3 (D), R13.2; also elsewhere on the board
/Interface /SWCLK/TCK: R24.2; also elsewhere on the board
/Interface /SWDIO/TMS: R25.2; also elsewhere on the board
/Interface /TDO: R26.2; also elsewhere on the board
/Interface /TRST: R28.2; also elsewhere on the board
/Interface /UART_DTR: R32.2; also elsewhere on the board
/Interface /UART_RTS: R33.2; also elsewhere on the board
/Interface /UART_RX: R31.2; also elsewhere on the board
/Interface /UART_TX: R30.2; also elsewhere on the board
/SRST: Q1.1 (G), R3.1; also elsewhere on the board
/SWCLK/TCK: U2.3 (A); also elsewhere on the board
/SWDIO_DIR: U3.5 (DIR); also elsewhere on the board
/SWDIO/TMS: U3.3 (A); also elsewhere on the board
/TDI: U5.3 (A); also elsewhere on the board
/TDO: U4.3 (A); also elsewhere on the board
/TRST: U6.3 (A); also elsewhere on the board
/UART_DTR: U11.3 (A); also elsewhere on the board
/UART_RTS: U12.3 (A); also elsewhere on the board
/UART_RX: U9.3 (A); also elsewhere on the board
/UART_TX: U8.3 (A); also elsewhere on the board
GND: C24.1, C25.2, C26.1, C27.2, C28.1, C29.2, C30.1, C31.2, C32.1, C33.2, C36.1, C37.2, C38.1, C39.2, C42.1, C43.2, C44.1, C45.2, Q1.2 (S), R3.2, U2.2 (GND), U3.2 (GND), U4.2 (GND), U4.5 (DIR), U5.2 (GND), U6.2 (GND), U8.2 (GND), U9.2 (GND), U9.5 (DIR), U11.2 (GND), U12.2 (GND); also elsewhere on the board
unnamed: R24.1, U2.4 (B)
unnamed: R25.1, U3.4 (B)
unnamed: R26.1, U4.4 (B)
unnamed: R27.1, U5.4 (B)
unnamed: R28.1, U6.4 (B)
unnamed: R30.1, U8.4 (B)
unnamed: R31.1, U9.4 (B)
unnamed: R32.1, U11.4 (B)
unnamed: R33.1, U12.4 (B)
TRANS_VCC: R13.1; also elsewhere on the board
VEE: C25.1, C27.1, C29.1, C31.1, C33.1, C37.1, C39.1, C43.1, C45.1, U2.6 (VCCB), U3.6 (VCCB), U4.6 (VCCB), U5.6 (VCCB), U6.6 (VCCB), U8.6 (VCCB), U9.6 (VCCB), U11.6 (VCCB), U12.6 (VCCB); also elsewhere on the board

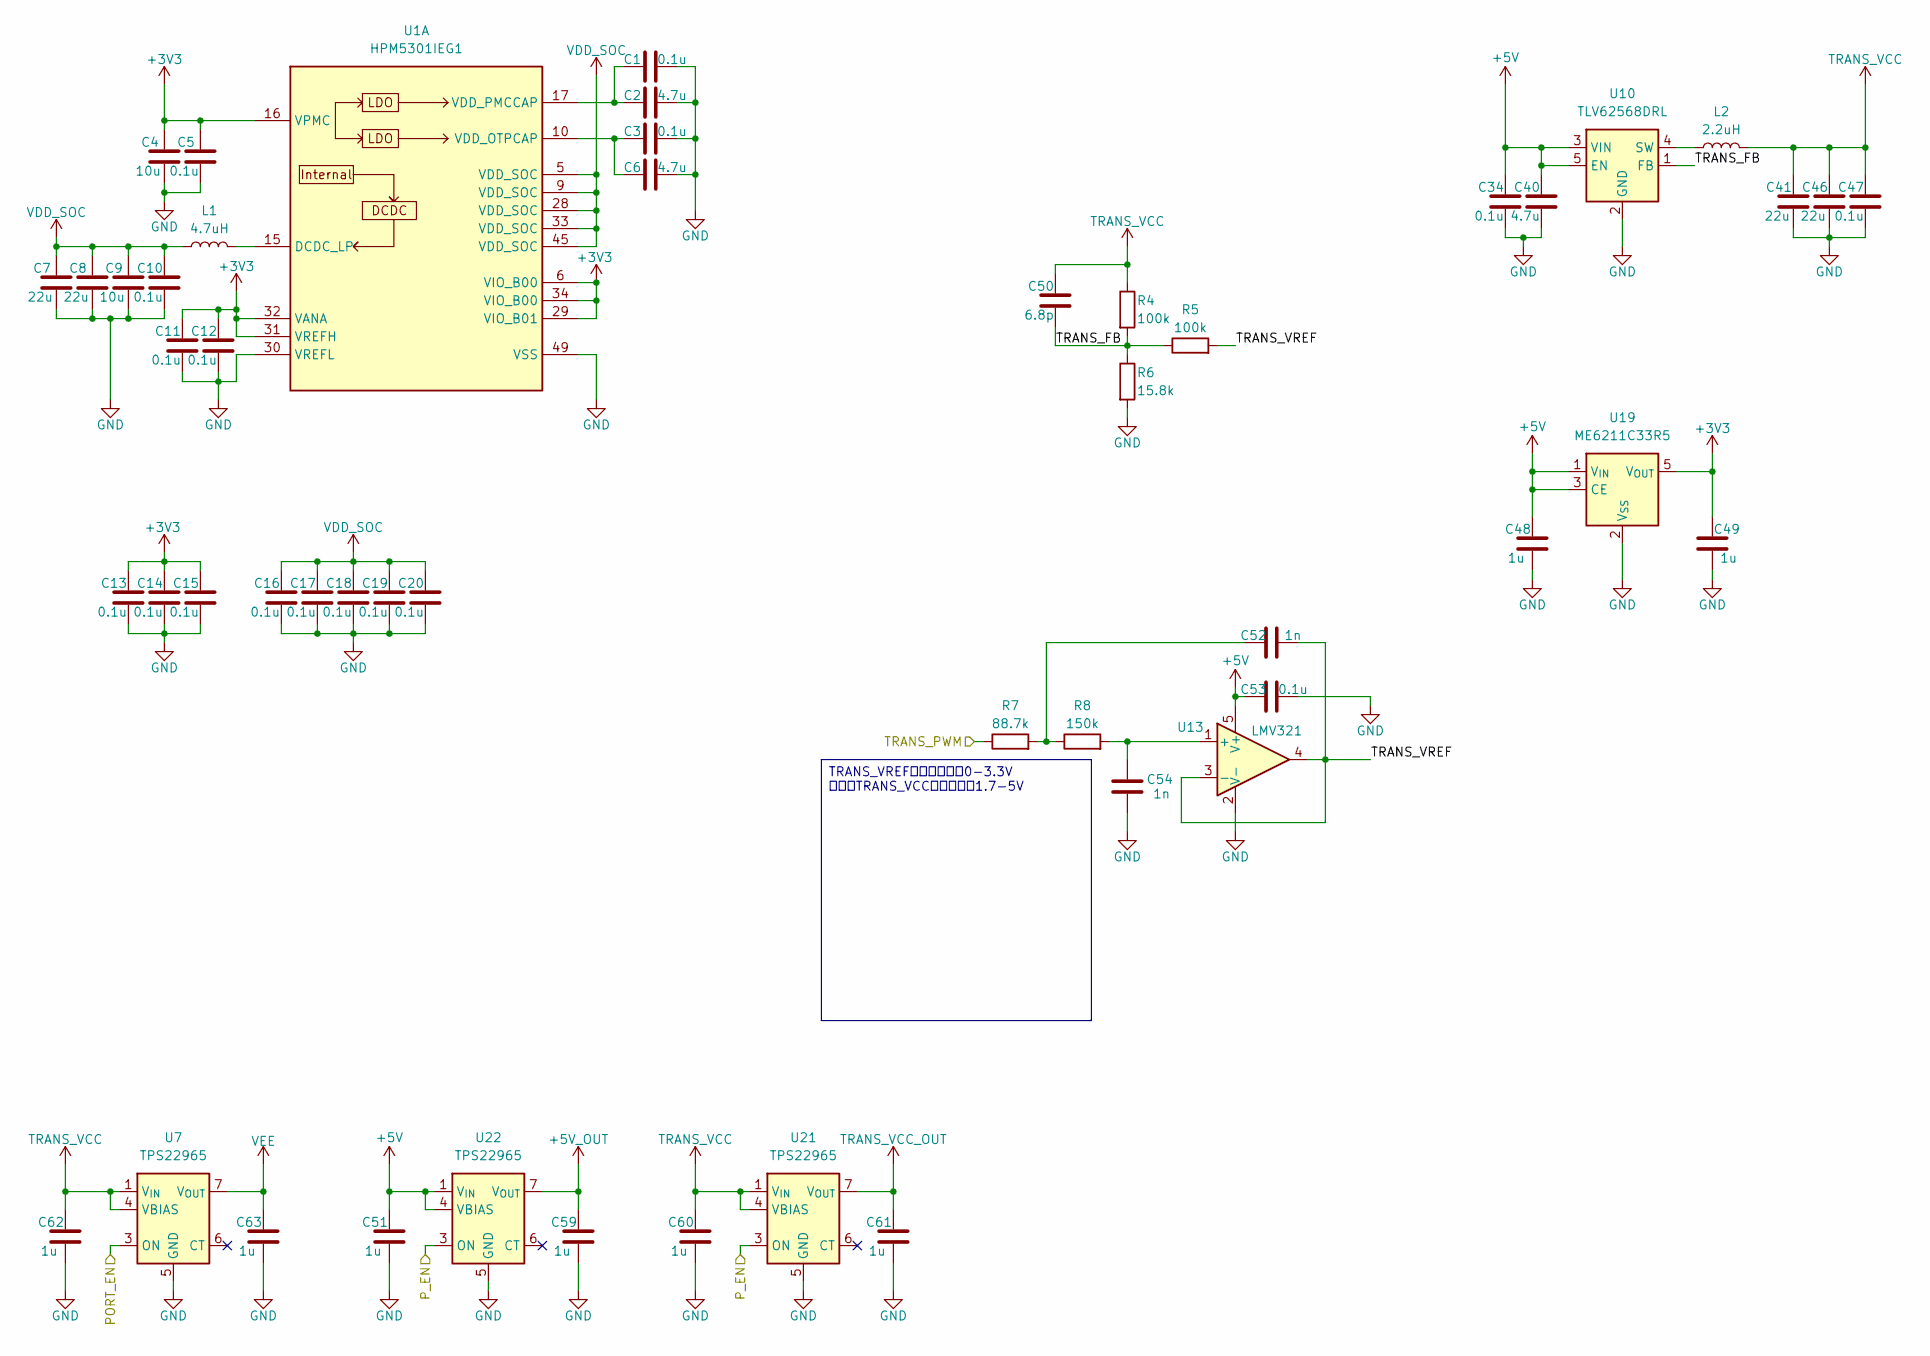
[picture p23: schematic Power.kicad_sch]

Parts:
C1, C3, C5, C10, C11, C12, C13, C14, C15, C16, C17, C18, C19, C20, C34, C47, C53: 0.1u; C_0402_1005Metric
C2, C6, C40: 4.7u; C_0402_1005Metric
C4, C9: 10u; C_0402_1005Metric
C7, C8: 22u; C_0402_1005Metric
C41, C46: 22u; C_0603_1608Metric
C48, C49, C51, C59, C60, C61, C62, C63: 1u; C_0402_1005Metric
C50: 6.8p; C_0402_1005Metric
C52, C54: 1n; C_0402_1005Metric
L1: 4.7uH; L_Murata_DFE201610P
L2: 2.2uH; L_Murata_DFE201610P
R4, R5: 100k; R_0402_1005Metric
R6: 15.8k; R_0402_1005Metric
R7: 88.7k; R_0402_1005Metric
R8: 150k; R_0402_1005Metric
U1: HPM5301IEG1; QFN-48-1EP_6x6mm_P0.4mm_EP4.2x4.2mm
U7, U21, U22: TPS22965; WSON-8-1EP_2x2mm_P0.5mm_EP0.9x1.6mm
U10: TLV62568DRL; SOT-563
U13: LMV321; SOT-353_SC-70-5
U19: ME6211C33R5; SOT-353_SC-70-5

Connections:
+3V3: C4.1, C5.1, C11.1, C12.1, C13.1, C14.1, C15.1, C49.1, U1.6 (VIO_B00), U1.16 (VPMC), U1.29 (VIO_B01), U1.31 (VREFH), U1.32 (VANA), U1.34 (VIO_B00), U19.5 (V_{OUT}); also elsewhere on the board
+5V: C34.1, C40.1, C48.1, C51.1, C53.1, U10.3 (VIN), U10.5 (EN), U13.5 (V+), U19.1 (V_{IN}), U19.3 (CE), U22.1 (V_{IN}), U22.2 (V_{IN}), U22.4 (VBIAS); also elsewhere on the board
+5V_OUT: C59.1, U22.7 (V_{OUT}), U22.8 (V_{OUT}); also elsewhere on the board
/PORT_EN: U7.3 (ON); also elsewhere on the board
/P_EN: U21.3 (ON), U22.3 (ON); also elsewhere on the board
/Power/TRANS_FB: C50.2, R4.2, R5.1, R6.1, U10.1 (FB)
/Power/TRANS_VREF: C52.2, R5.2, U13.3 (-), U13.4
/TRANS_PWM: R7.1; also elsewhere on the board
GND: C1.2, C2.2, C3.2, C4.2, C5.2, C6.2, C7.2, C8.2, C9.2, C10.2, C11.2, C12.2, C13.2, C14.2, C15.2, C16.2, C17.2, C18.2, C19.2, C20.2, C34.2, C40.2, C41.2, C46.2, C47.2, C48.2, C49.2, C51.2, C53.2, C54.2, C59.2, C60.2, C61.2, C62.2, C63.2, R6.2, U1.30 (VREFL), U1.49 (VSS), U7.5 (GND), U7.9 (EP), U10.2 (GND), U13.2 (V-), U19.2 (V_{SS}), U21.5 (GND), U21.9 (EP), U22.5 (GND), U22.9 (EP); also elsewhere on the board
unnamed: C52.1, R7.2, R8.1
unnamed: L1.2, U1.15 (DCDC_LP)
unnamed: C3.1, C6.1, U1.10 (VDD_OTPCAP)
unnamed: C1.1, C2.1, U1.17 (VDD_PMCCAP)
unnamed: L2.1, U10.4 (SW)
unnamed: C54.1, R8.2, U13.1 (+)
TRANS_VCC: C41.1, C46.1, C47.1, C50.1, C60.1, C62.1, L2.2, R4.1, U7.1 (V_{IN}), U7.2 (V_{IN}), U7.4 (VBIAS), U21.1 (V_{IN}), U21.2 (V_{IN}), U21.4 (VBIAS); also elsewhere on the board
TRANS_VCC_OUT: C61.1, U21.7 (V_{OUT}), U21.8 (V_{OUT}); also elsewhere on the board
VDD_SOC: C7.1, C8.1, C9.1, C10.1, C16.1, C17.1, C18.1, C19.1, C20.1, L1.1, U1.5 (VDD_SOC), U1.9 (VDD_SOC), U1.28 (VDD_SOC), U1.33 (VDD_SOC), U1.45 (VDD_SOC)
VEE: C63.1, U7.7 (V_{OUT}), U7.8 (V_{OUT}); also elsewhere on the board

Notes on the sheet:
TRANS_VREF的电压范围为0-3.3V 映射到TRANS_VCC上的电压为1.7-5V

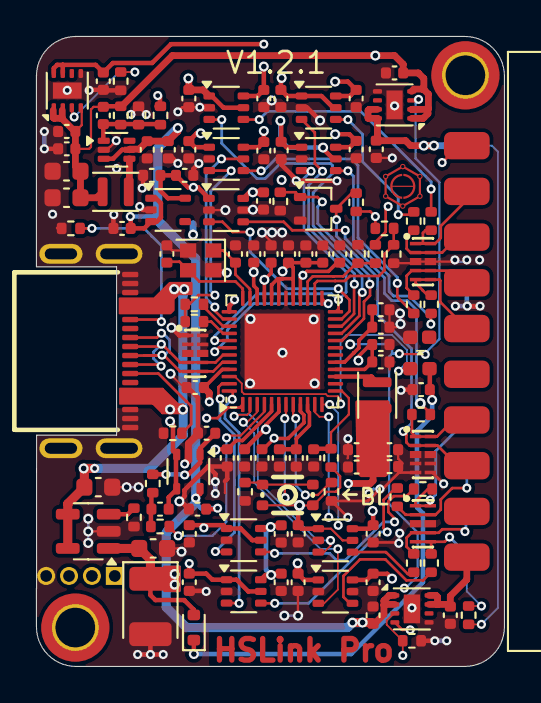
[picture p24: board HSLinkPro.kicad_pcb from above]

Board: 4 copper layers, 26.0 x 35.0 mm, 124 parts (0 on the bottom side), 70 nets.

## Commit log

2025-04-12 降低工艺需求
    [HSLinkPro.kicad_pcb]
2025-04-21 fix: 1.2.1 修复UART RX未上拉问题
    [HSLinkPro.kicad_pcb, Interface.kicad_sch]
